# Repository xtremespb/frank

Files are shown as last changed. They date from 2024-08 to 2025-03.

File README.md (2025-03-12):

# FRANK

FRANK is a versatile hardware emulation platform based on Raspberry Pico and Raspberry Zero. It is a hardware fork of the [Murmulator](https://murmulator.ru/) project by [Alex Ekb](https://t.me/Alex_Eburg), incorporating numerous additional features.

The name "FRANK" is derived from "Frankenstein" as it integrates various components from different projects, similar to how Dr. Frankenstein created his monster from different parts. This combination enables FRANK to offer a unique and powerful set of capabilities.

## Supported Platforms

FRANK supports emulation for a variety of platforms, including:

* ZX Spectrum (48K, 128K and other models, including clones)
* IBM PC XT 8088
* BK-0011М (soviet 8 bit home computer)
* Radio 86RK (soviet 8 bit home computer)
* Atari 800
* NES/Famicom (also known as Dendy)
* Sega Master System
* Sega Game Gear
* NEC PC Engine / TurboGrafx 16
* Sega MegaDrive / Genesis
* Nintendo GameBoy
* Nintendo GameBoy Color
* Watara Supervision
* Atari Lynx
* Bandai Wonderswan
* NeoGeo Pocket Color
* Picomite MMBasic
* VersaTerm
* DOOM
* Macintosh 512K
* MurmulatorOS

## FRANK Models

Currently there are the following versions of FRANK available:

* [FRANK M1](./hardware/frank_m1) (latest hardware revision: 1.14)
* [FRANK M2](./hardware/frank_m2) (latest hardware revision: 1.02)
* [MiniFRANK RM1](./hardware/minifrank_rm1) (latest hardware revision: 2.01)
* [TurboFRANK](./hardware/turbofrank) (latest hardware revision: 1.02)

## Side Projects

* [HDMI2VGA](./hardware/hdmi2vga) - HDMI to VGA/Soft Composite passive adaptor (latest hardware revision: 2.01)
* [USB2PS2](./hardware/usb2ps2) - USB to PS/2 adapter built on RP2040-Zero (latest hardware revision: 1.03)
* [Protea](./hardware/protea) - hardware fork of [VersaTerm](https://github.com/dhansel/VersaTerm) DIY terminal built on plain RP2040 chip (latest hardware revision: 2.03)

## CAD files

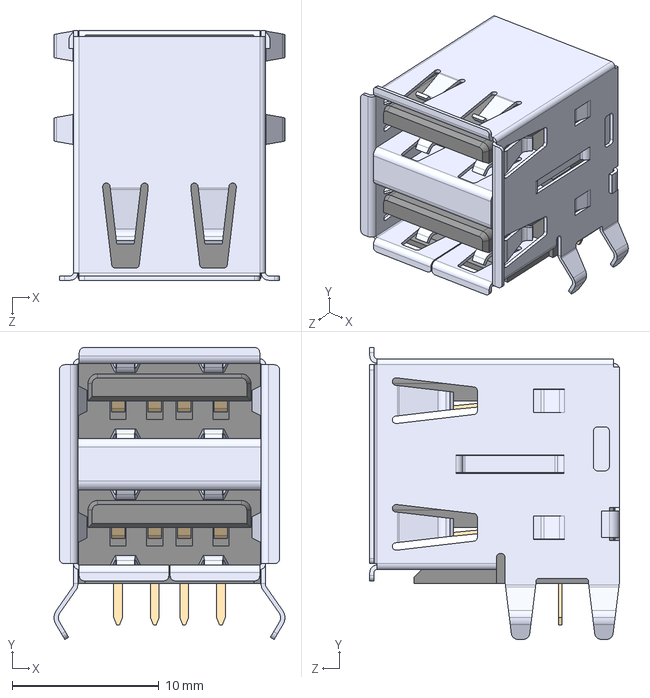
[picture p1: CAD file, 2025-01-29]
hardware/frank_rm1z/3D/USB1035-GF-P-0-B-B.stp
15.7 x 19.9 x 17.0 mm

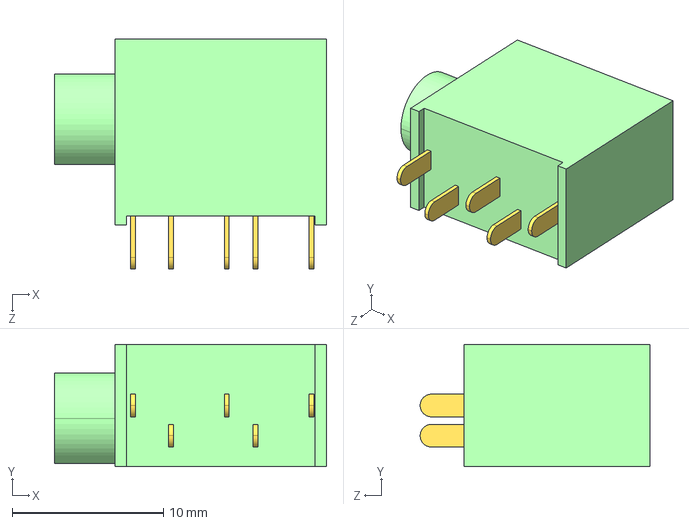
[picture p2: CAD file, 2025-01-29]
hardware/minifrank_rm1/3D/PJ325.step
18.0 x 8.10 x 15.2 mm

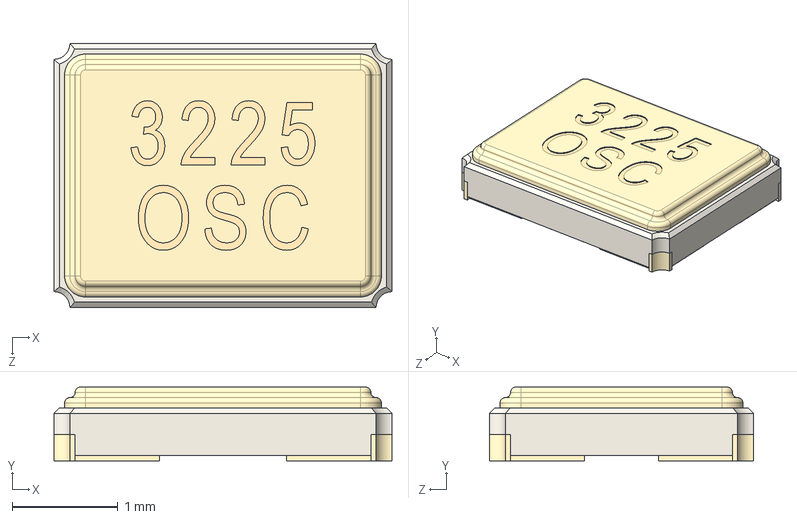
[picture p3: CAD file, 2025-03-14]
hardware/minifrank_rm24/3D/3225 SMD Crystal Oscillator.STEP
3.20 x 0.7 x 2.50 mm

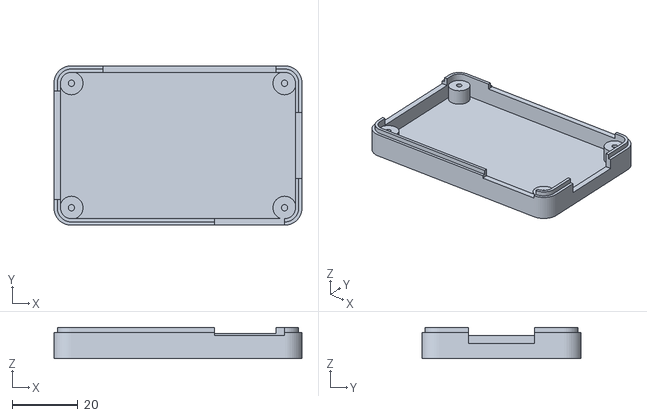
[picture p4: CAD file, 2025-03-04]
hardware/protea/CASE/2_xx/bottom.stl
75.3 x 48.4 x 9.50

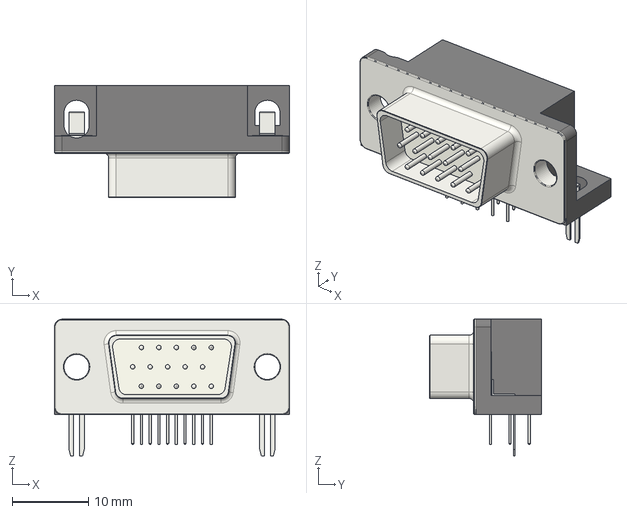
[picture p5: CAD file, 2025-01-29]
hardware/frank_rm1z/3D/DSUB-15-HD_Male_Horizontal_P2.29x1.98mm_EdgePinOffset3.03mm_Housed_MountingHolesOffset4.94mm.step
30.8 x 14.7 x 17.9 mm

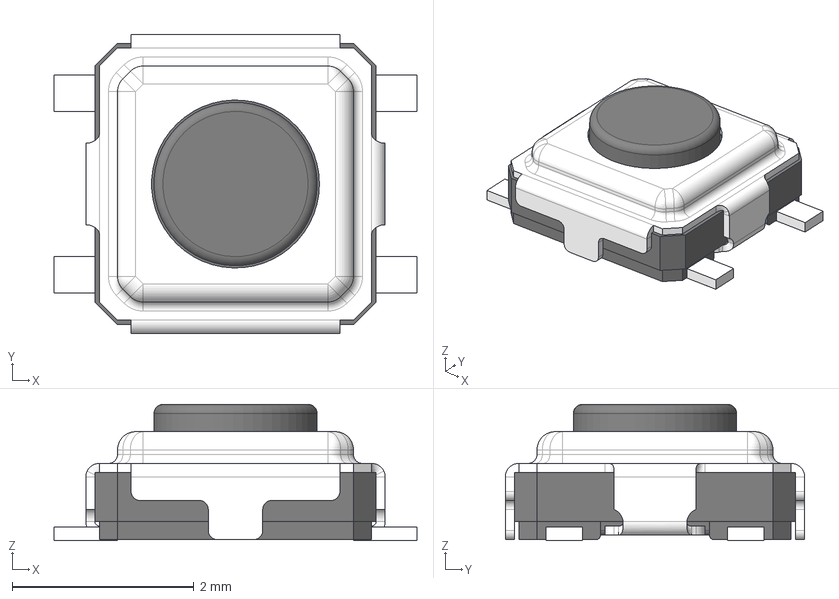
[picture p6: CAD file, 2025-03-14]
hardware/minifrank_rm24/3D/Ts-1233_1.5.stp
4.00 x 3.30 x 1.50 mm

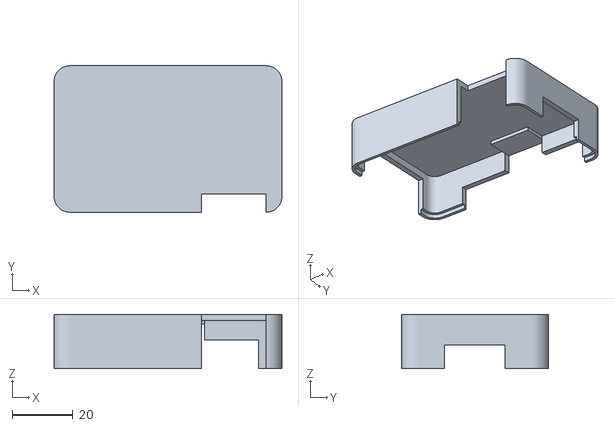
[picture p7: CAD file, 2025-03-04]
hardware/protea/CASE/2_xx/top.stl
75.3 x 48.4 x 18.0

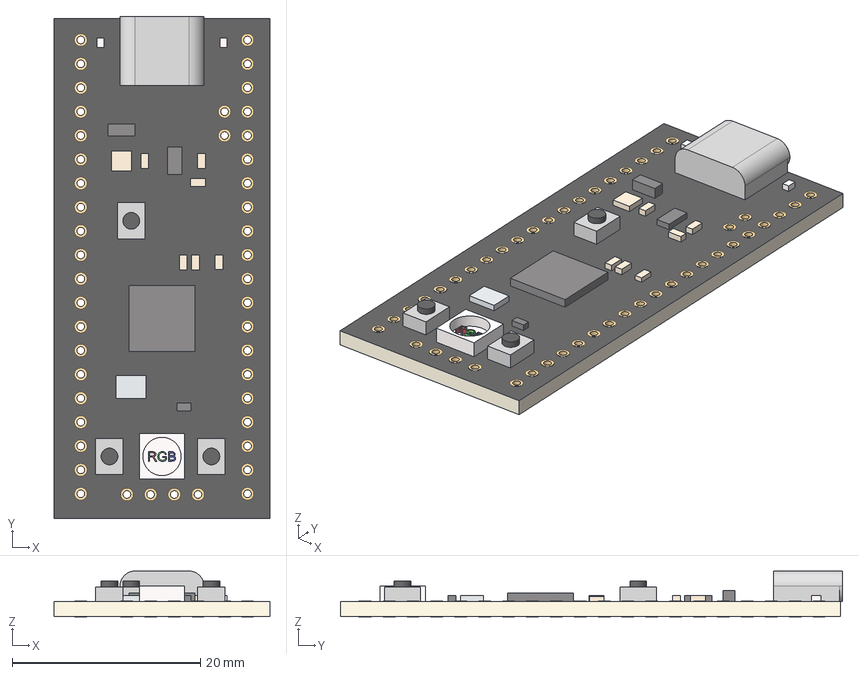
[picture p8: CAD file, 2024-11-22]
hardware/frank_rm1z/3D/PICO Clone-Black .step
22.9 x 53.3 x 4.88 mm

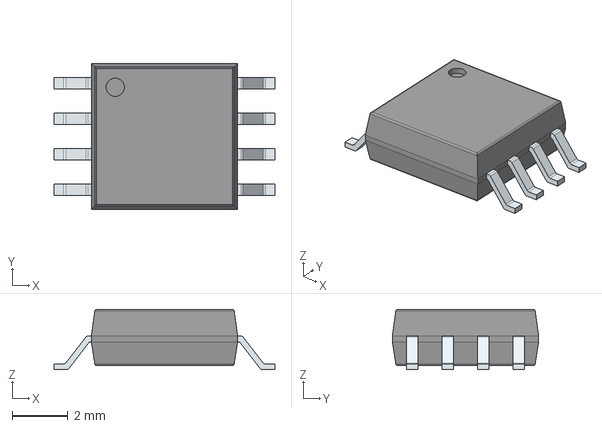
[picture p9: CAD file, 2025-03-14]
hardware/minifrank_rm24/3D/W25Q128JVSIQ.stp
7.90 x 5.23 x 2.16 mm
PinsArrayLR

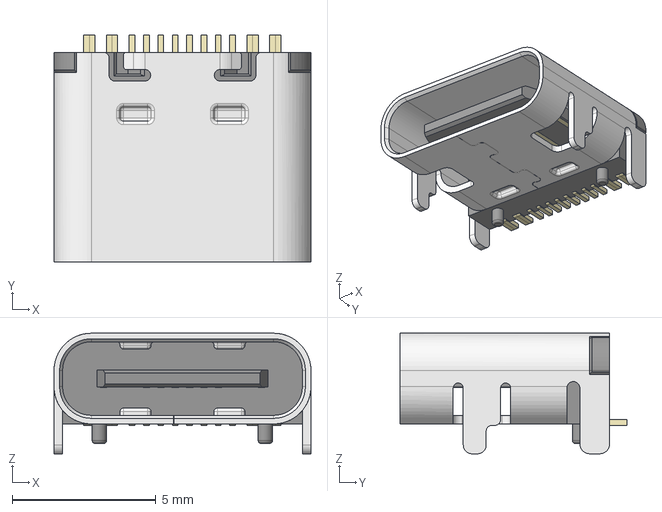
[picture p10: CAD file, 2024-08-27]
hardware/frank_rm1z/3D/HRO_TYPE-C-31-M-12.step
8.95 x 7.90 x 4.20 mm

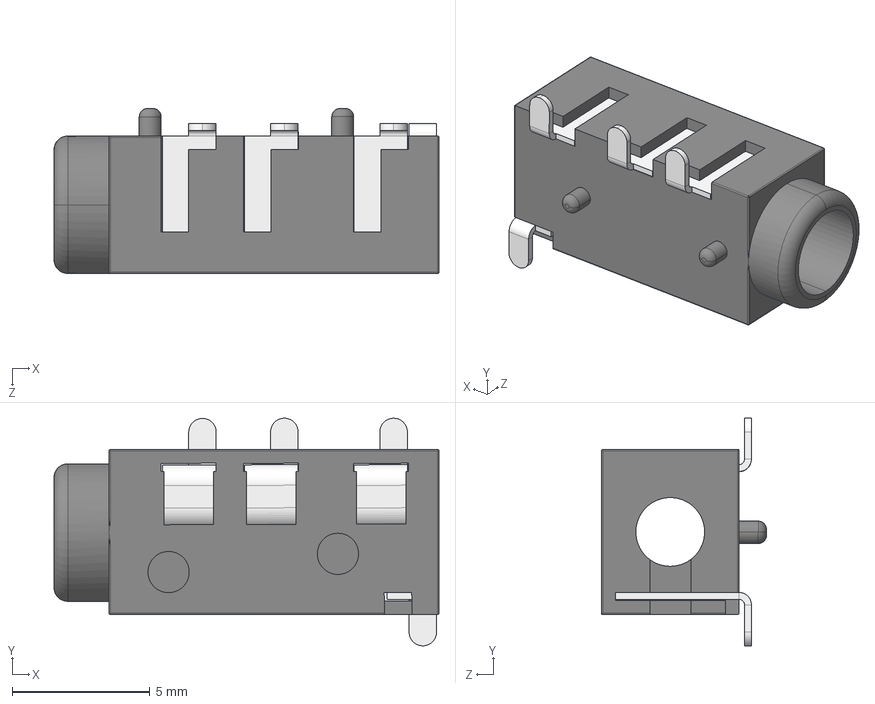
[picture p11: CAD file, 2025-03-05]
hardware/minifrank_rm24/3D/PJ320D.STEP
14.0 x 8.28 x 6.00 mm
PJ320A
PJ320D-Pin x 3
PJ320D-Pin-B

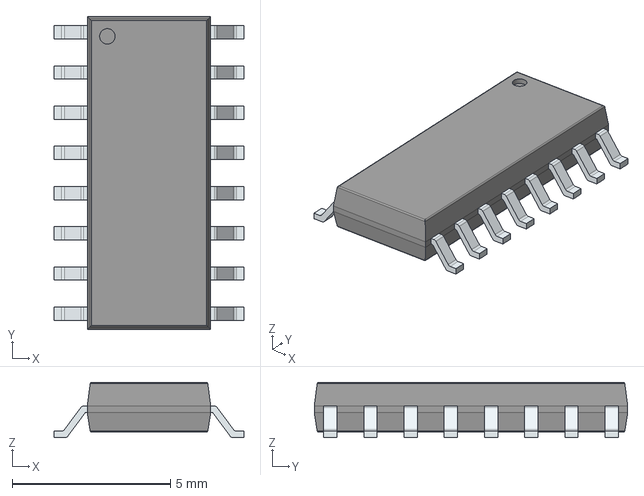
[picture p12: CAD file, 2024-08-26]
hardware/frank_rm1z/3D/MAX232CSE+.stp
6.00 x 9.90 x 1.75 mm
PinsArrayLR

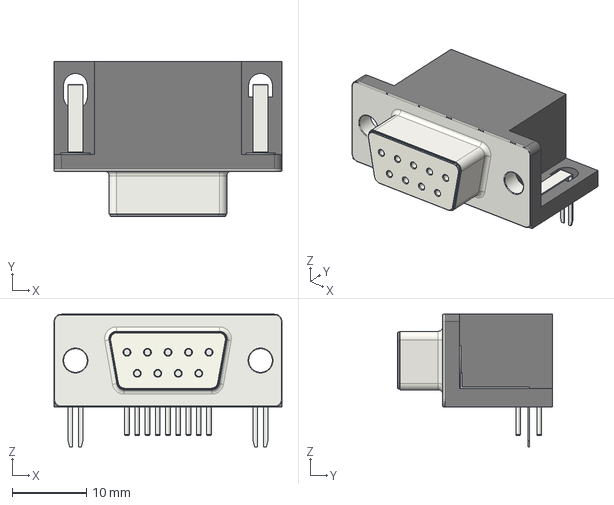
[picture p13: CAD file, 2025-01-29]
hardware/minifrank_rm24/3D/DSUB-9_Female_Horizontal_P2.77x2.84mm_EdgePinOffset9.90mm_Housed_MountingHolesOffset11.32mm.step
30.8 x 20.9 x 17.9 mm

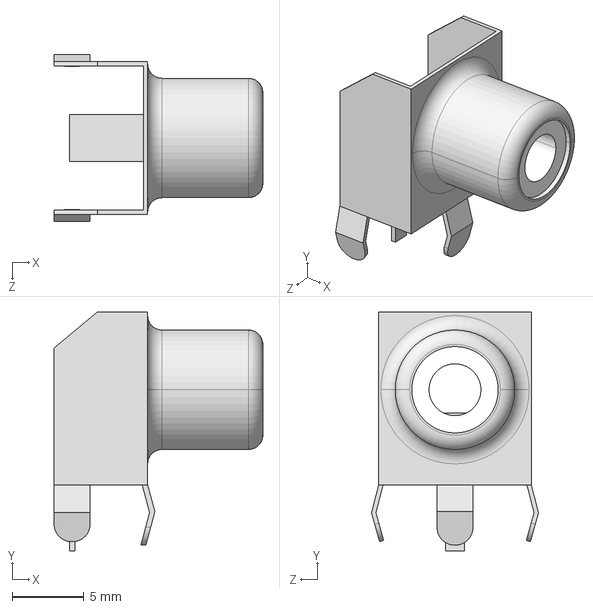
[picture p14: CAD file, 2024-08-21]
hardware/frank_rm1z/3D/CUI_DEVICES_RCJ-013.step
14.5 x 16.6 x 11.6 mm

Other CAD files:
hardware/frank_rm1z/3D/Mini-DIN-6P.step
hardware/frank_rm1z/3D/SJ1-3535NG.stp
hardware/minifrank_rm24/3D/SJ1-3535NG.stp
hardware/frank/3D/Mini-DIN-6P.step
hardware/frank/3D/SJ1-3535NG.stp
hardware/minifrank/3D/Mini-DIN-6P.step
hardware/minifrank/3D/SJ1-3535NG.stp
hardware/minifrank_rm1/3D/Mini-DIN-6P.step
hardware/minifrank_rm1/3D/SJ1-3535NG.stp
hardware/minifrank_rm1/CASE/bottom.stl
hardware/minifrank_rm1/CASE/top.stl
hardware/minifrank_rm24/3D/47571-0001.stp
hardware/minifrank_rm24/3D/Mini-DIN-6P.step
hardware/turbofrank/CASE/bottom.stl
hardware/turbofrank/CASE/top.stl
hardware/usb2ps2/3D/Mini-DIN-6P.step
hardware/usb2ps2/3D/SJ1-3535NG.stp
hardware/usb2ps2/CASE/REV_1_0/bottom.stl
hardware/usb2ps2/CASE/REV_1_0/top.stl
hardware/valera/3D/Mini-DIN-6P.step

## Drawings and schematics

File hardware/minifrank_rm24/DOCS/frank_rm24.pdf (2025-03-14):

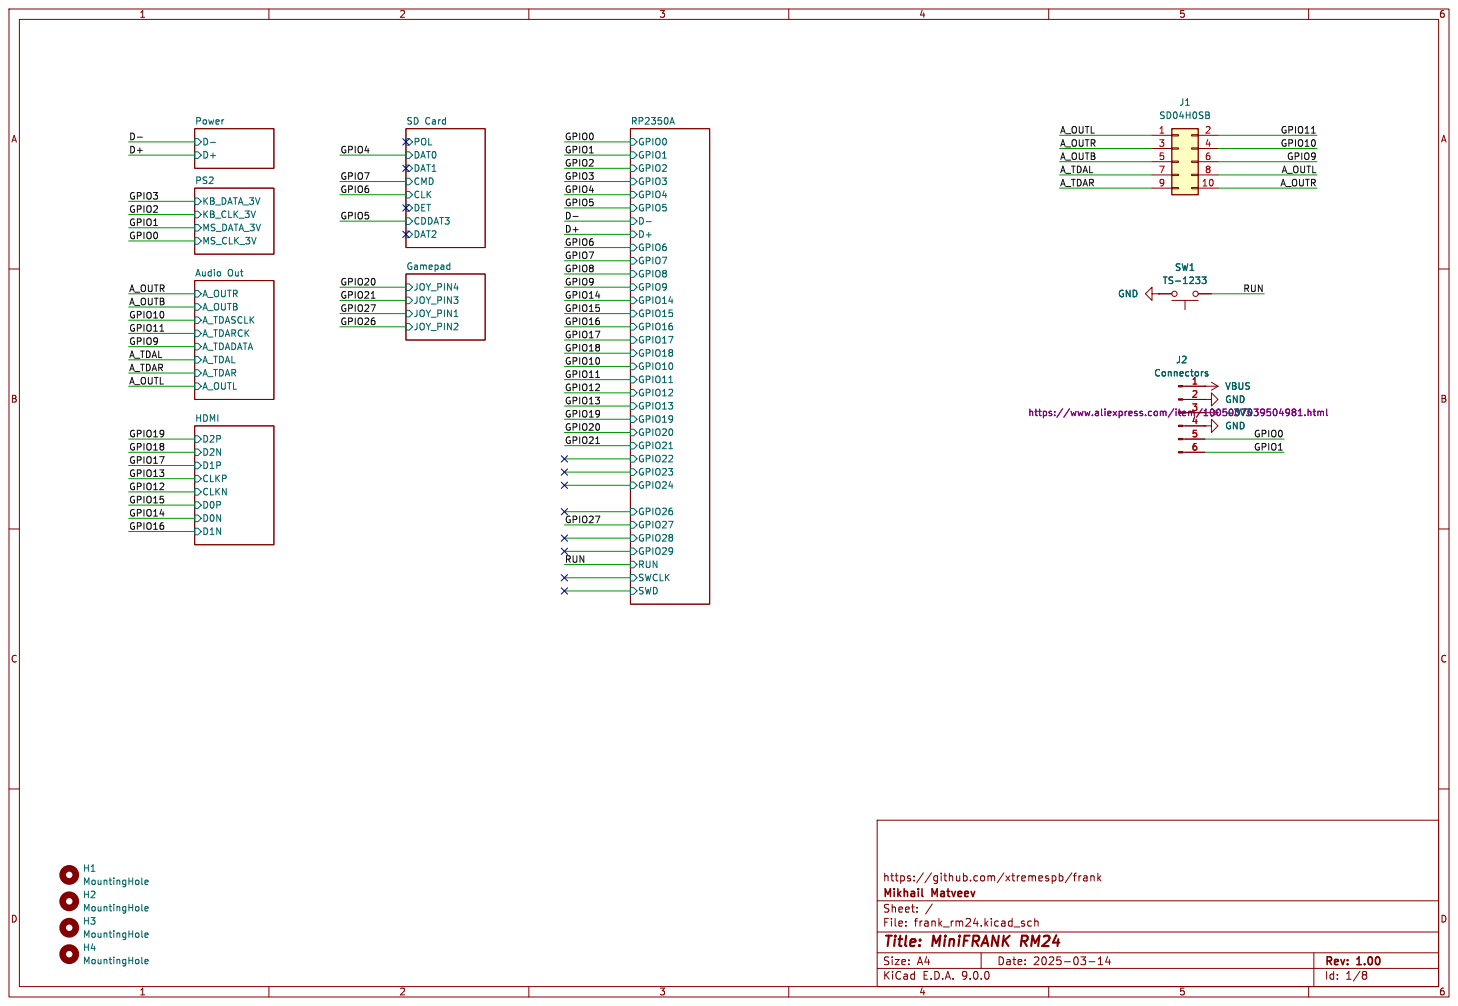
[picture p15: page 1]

J2 Connectors https://www.aliexpress.com/item/1005007039504981.html 123456 GND

https://github.com/xtremespb/frank

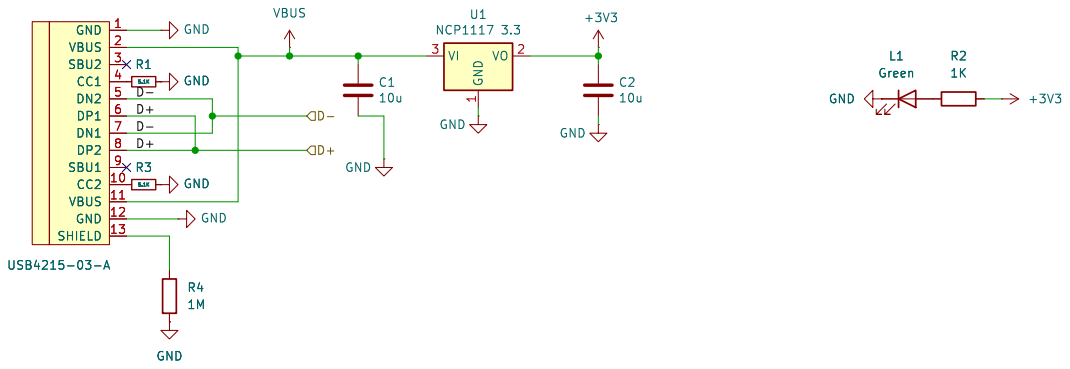
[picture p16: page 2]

https://github.com/xtremespb/frank

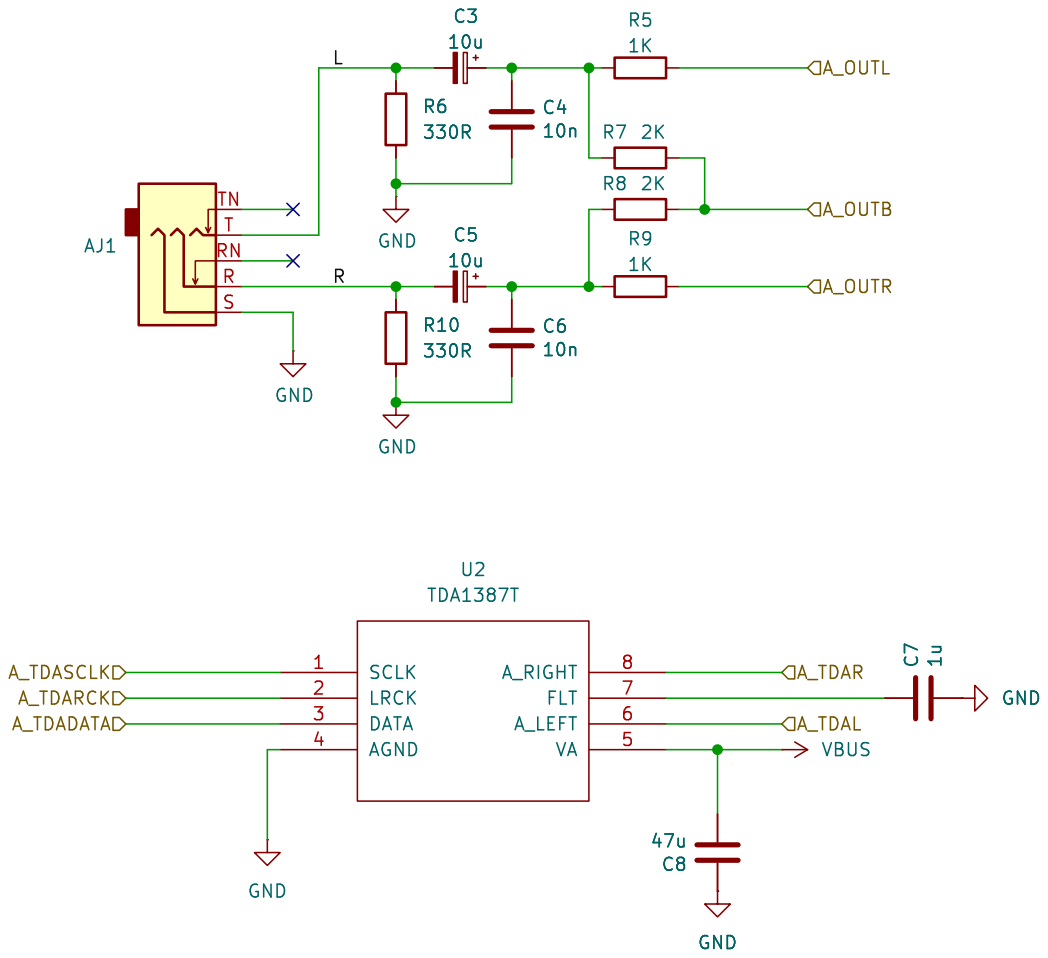
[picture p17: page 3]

https://github.com/xtremespb/frank

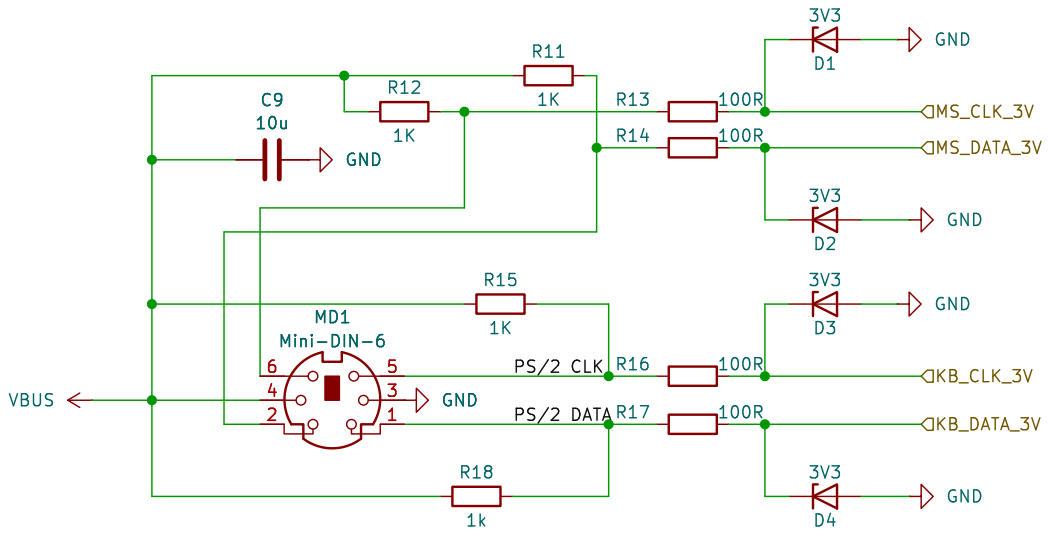
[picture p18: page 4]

PS/2 CLK MD1 Mini-DIN-6

https://github.com/xtremespb/frank

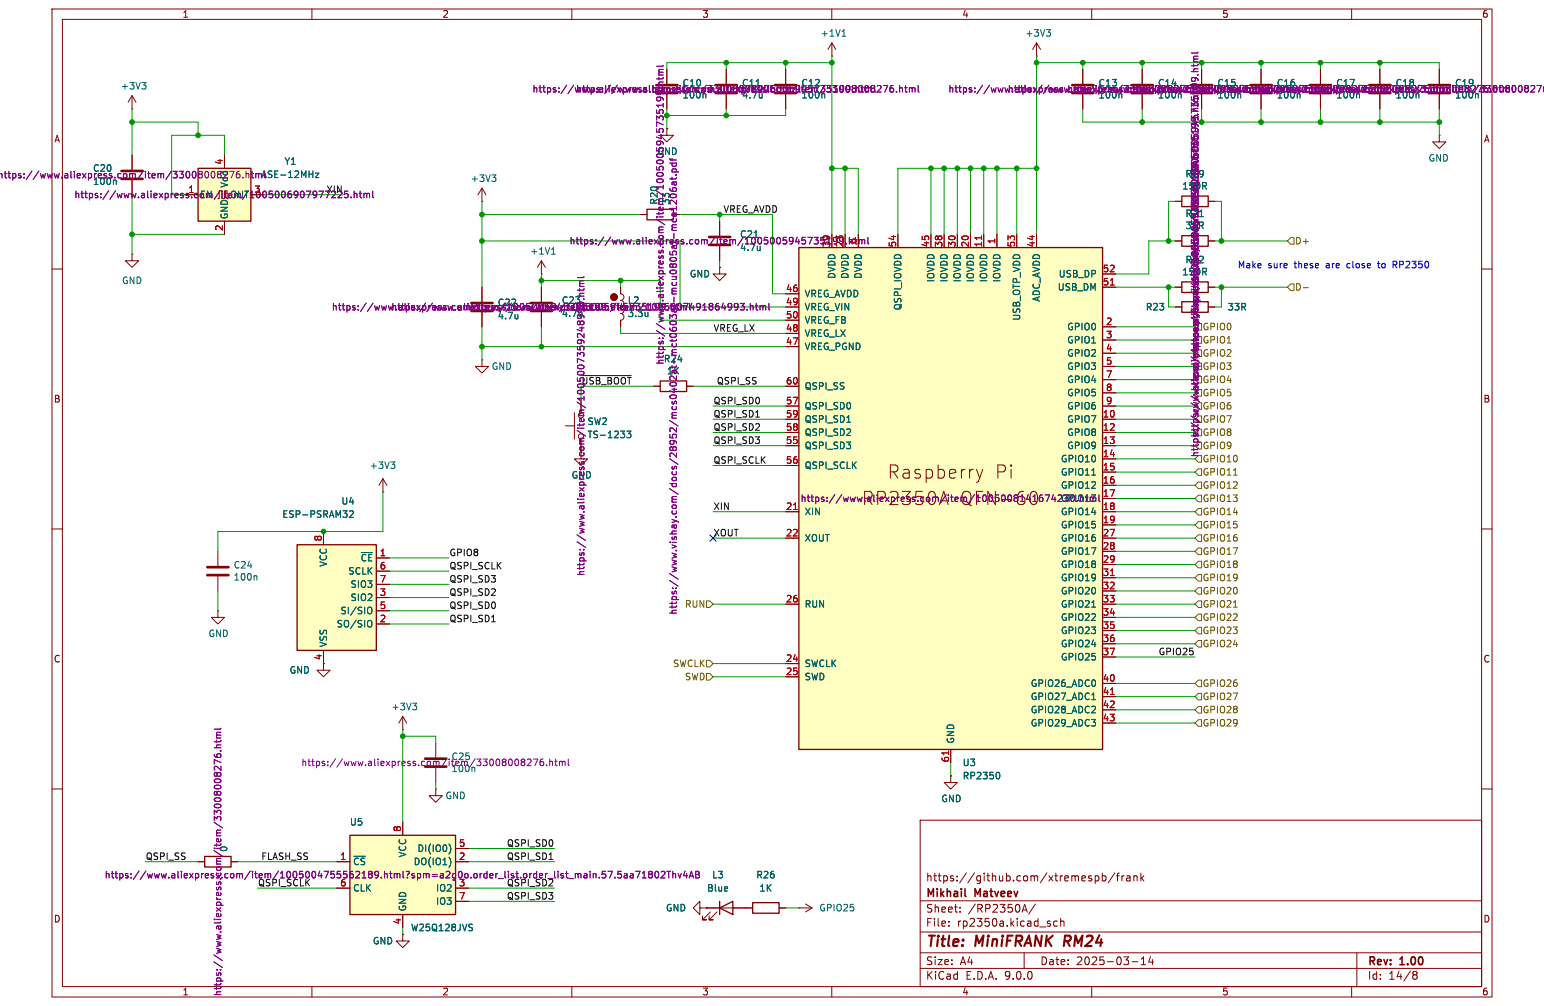
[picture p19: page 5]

100n https://www.aliexpress.com/item/33008008276.html GND GND

https://www.aliexpress.com/item/1005005945735199.html C11

4.7u https://www.aliexpress.com/item/1005005945735199.html C10

100n https://www.aliexpress.com/item/33008008276.htmlC14
100n GND

100n https://www.aliexpress.com/item/33008008276.html C14

100n https://www.aliexpress.com/item/33008008276.htmlC17

100n https://www.aliexpress.com/item/33008008276.html C16
150Rhttps://www.aliexpress.com/item/1005005945735199.html R21

100n https://www.aliexpress.com/item/33008008276.htmlC19

100n https://www.aliexpress.com/item/33008008276.html C18

100n https://www.aliexpress.com/item/33008008276.html
1Khttps://www.vishay.com/docs/28952/mcs0402at-mct0603at-mcu0805at-mca1206at.pdf C23

2 OUT 3 Y1 ASE-12MHz https://www.aliexpress.com/item/1005006907977225.html

6 QSPI_IOVDD 54 IOVDD 45 IOVDD 38 GND 61 IOVDD 30 IOVDD 20 IOVDD 11 IOVDD

https://www.aliexpress.com/item/1005007491864993.html

https://www.aliexpress.com/item/1005005945735199.html C22
https://www.aliexpress.com/item/1005007491864993.html GND

0 https://www.aliexpress.com/item/33008008276.html U4 ESP-PSRAM32 VCC

4 ~{CE}1 SCLK 6 SIO3 7 SIO2 3 SI/SIO 5 SO/SIO 2 U4 ESP-PSRAM32 R26

4 ~{CE}1 SCLK 6 SIO3 7 SIO2 3 SI/SIO 5 SO/SIO 2 GND

https://github.com/xtremespb/frank C24

100n https://www.aliexpress.com/item/33008008276.html +3V3

0 https://www.aliexpress.com/item/33008008276.html L3 Blue GND GPIO25

https://www.aliexpress.com/item/1005004755562189.html?spm=a2g0o.order_list.order_list_main.57.5aa71802Thv4AB

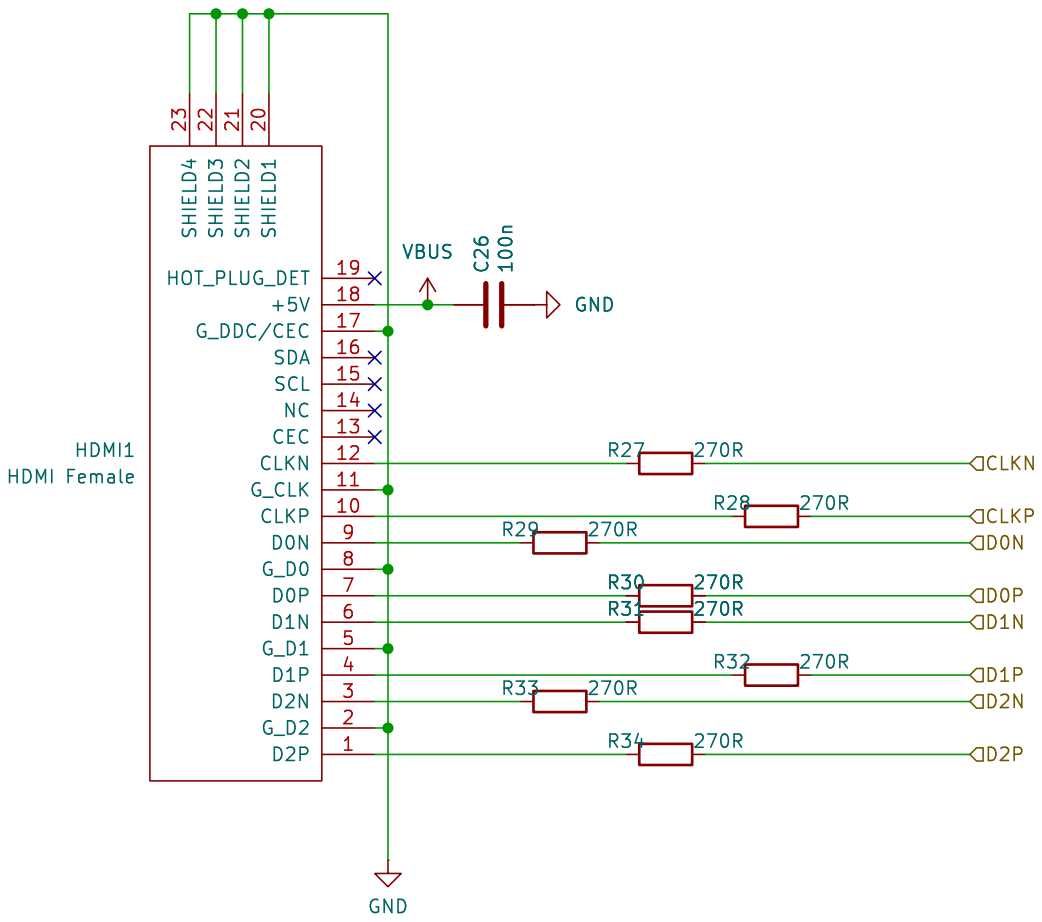
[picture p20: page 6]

https://github.com/xtremespb/frank

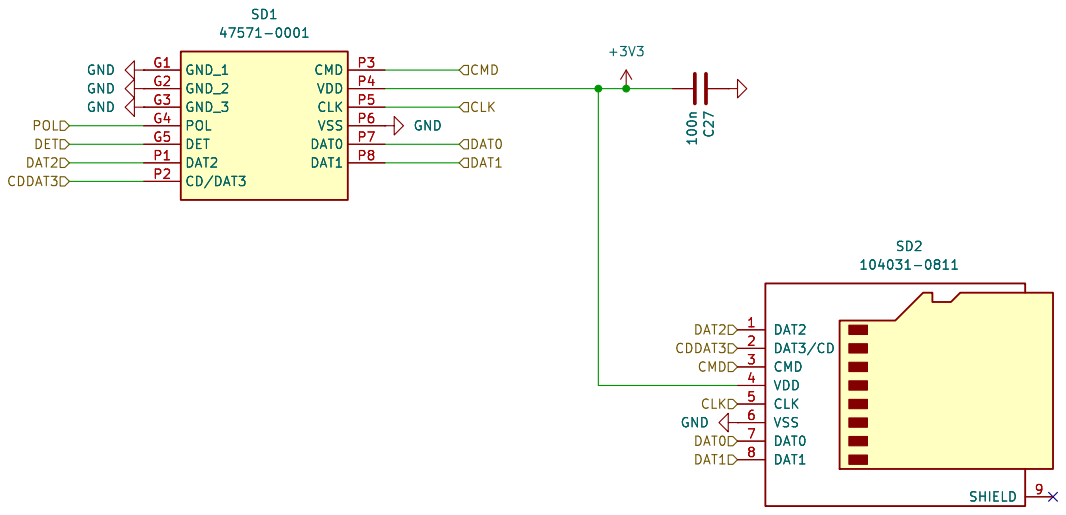
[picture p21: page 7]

https://github.com/xtremespb/frank

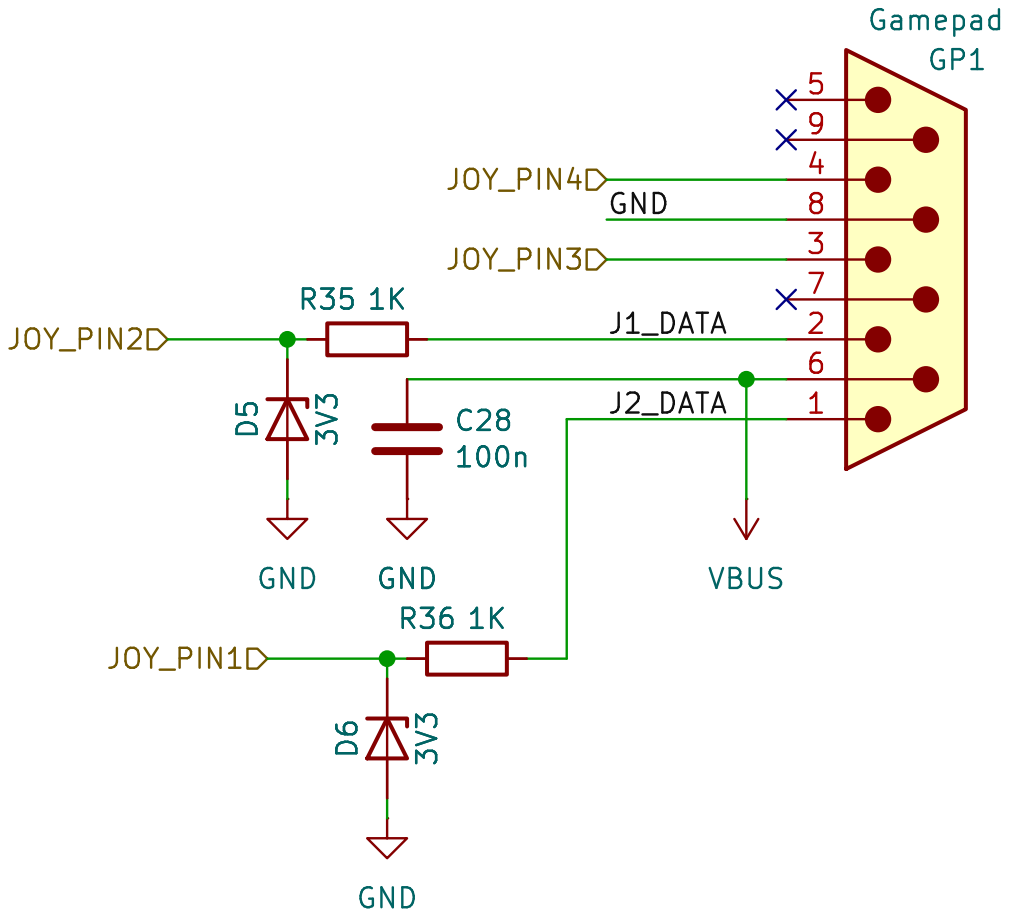
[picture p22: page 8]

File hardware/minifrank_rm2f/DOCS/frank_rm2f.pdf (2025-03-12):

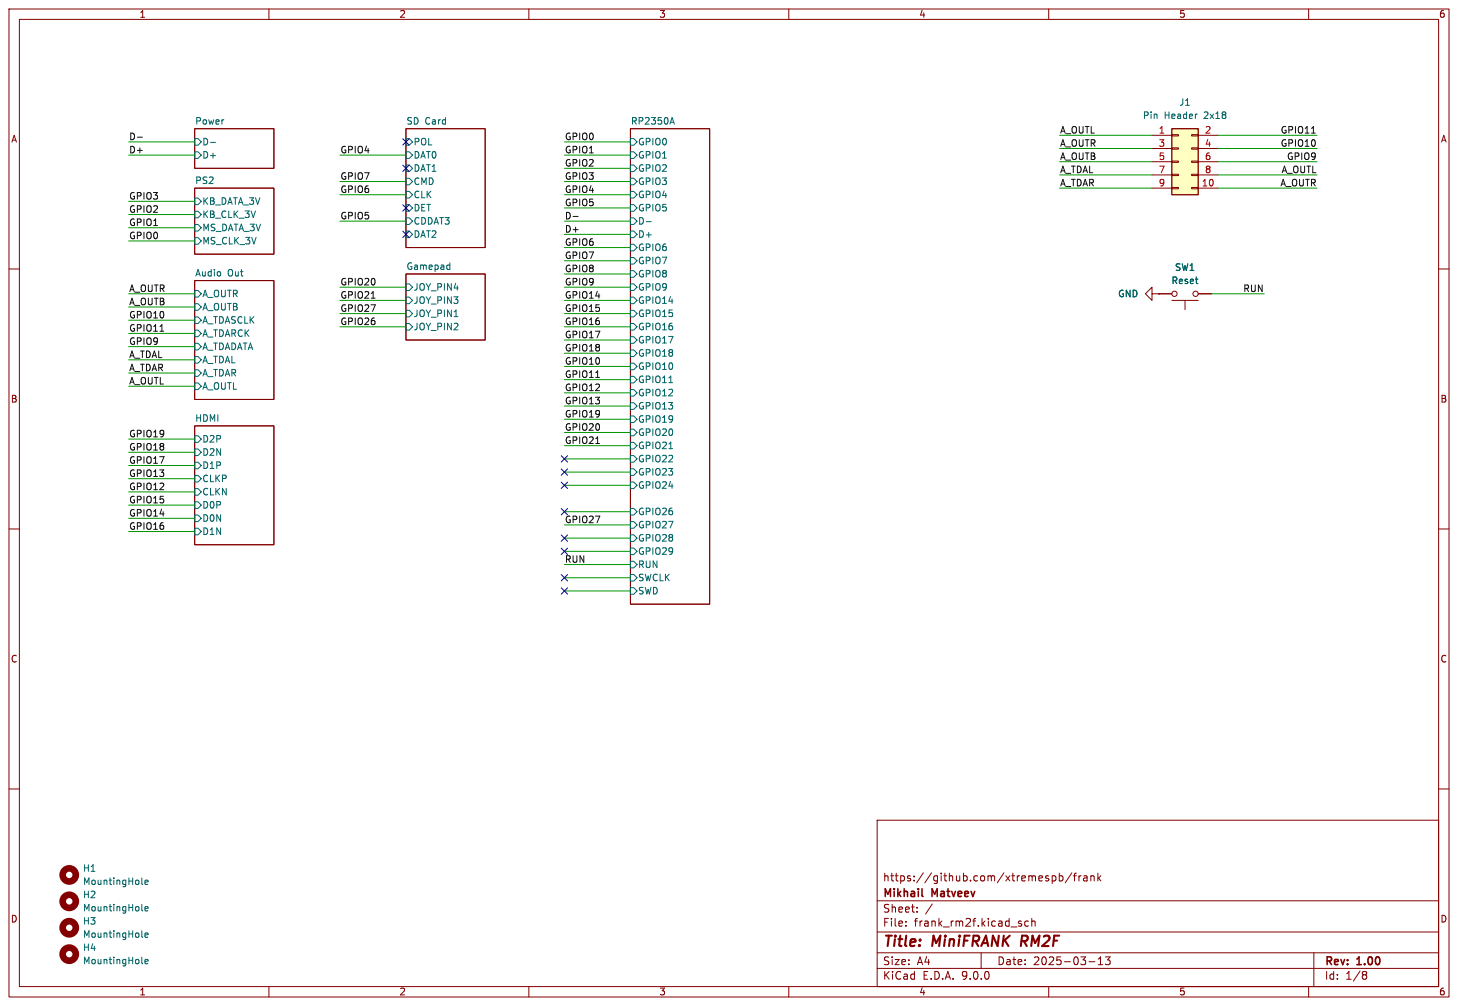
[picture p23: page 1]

CLK DET CDDAT3 DAT2 SD Card KB_DATA_3V

H3 MountingHole H4 MountingHole H2 MountingHole H1 MountingHole

https://github.com/xtremespb/frank

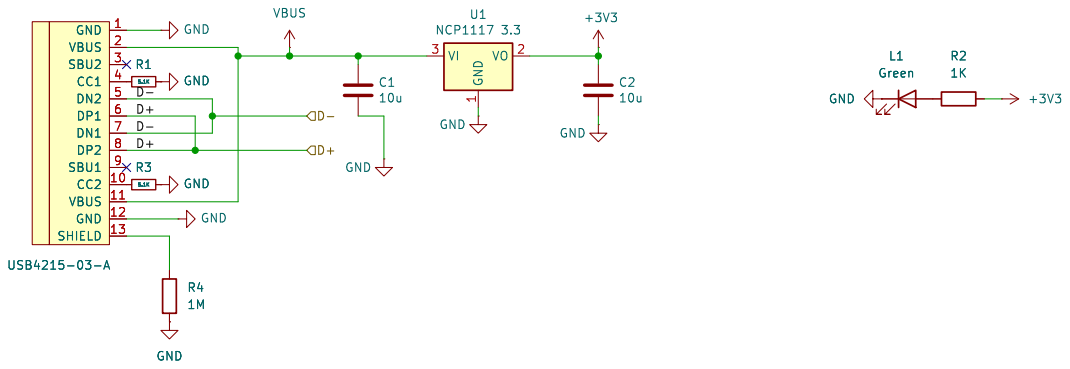
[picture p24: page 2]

https://github.com/xtremespb/frank

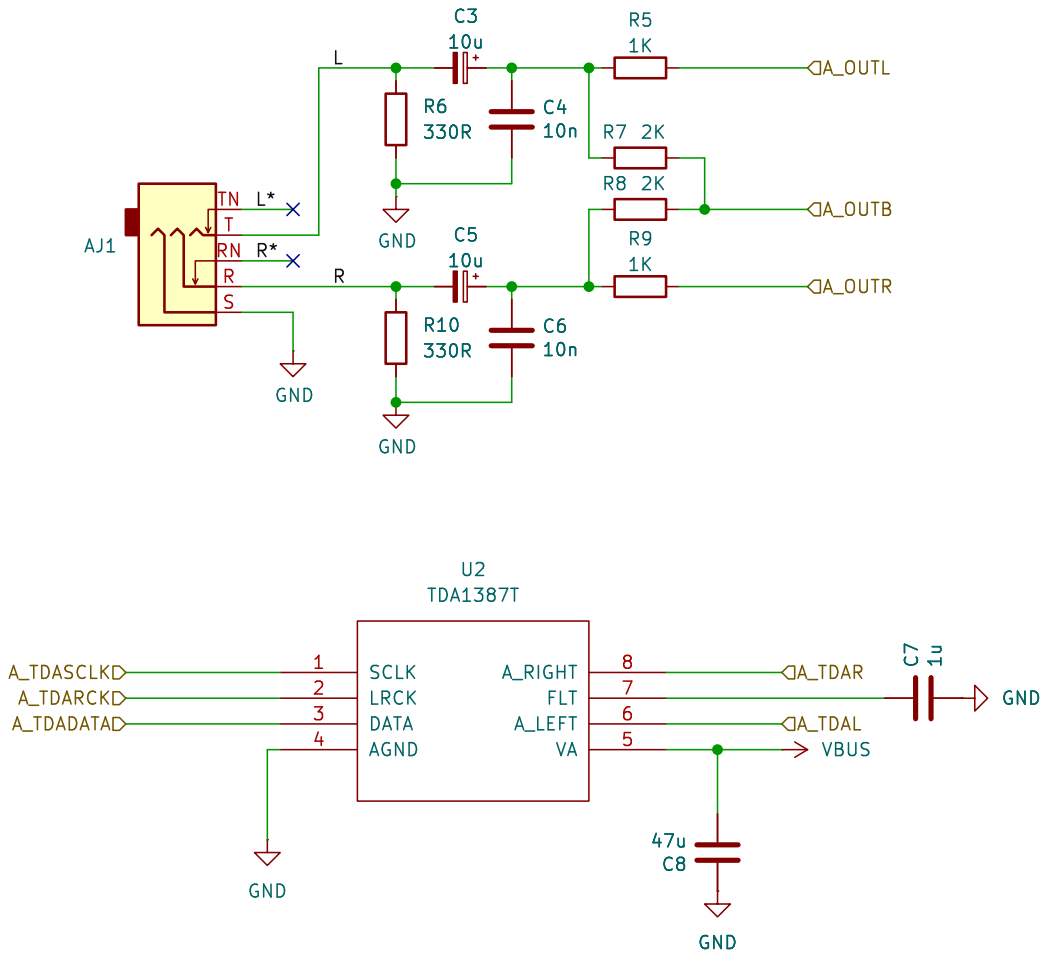
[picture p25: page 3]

https://github.com/xtremespb/frank GND


PS/2 CLK MD1 Mini-DIN-6

https://github.com/xtremespb/frank

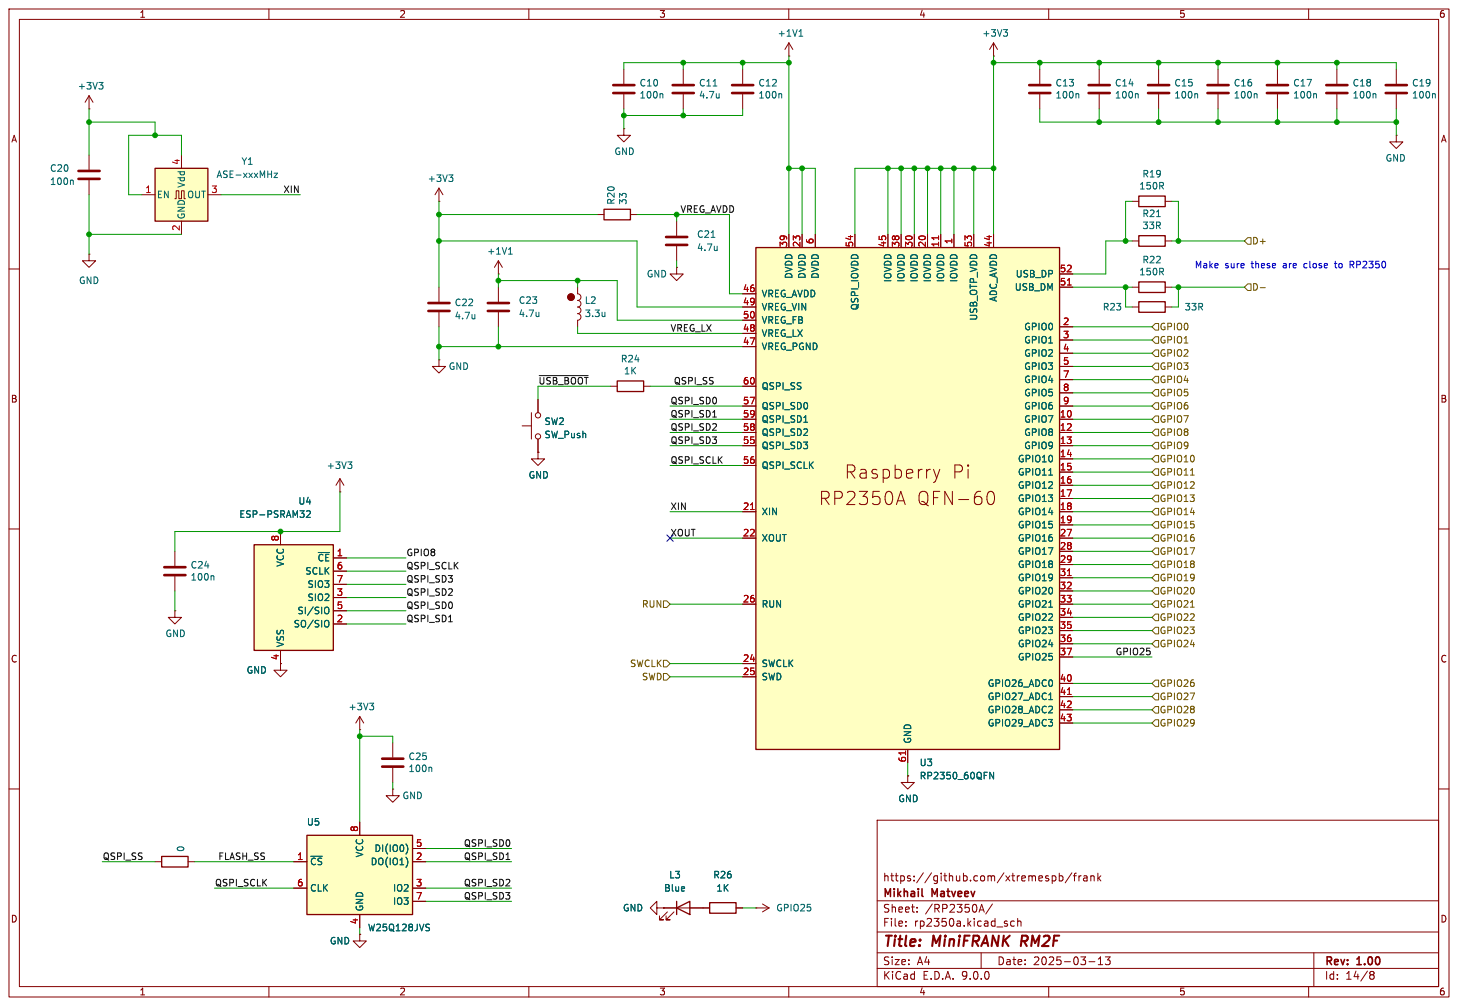
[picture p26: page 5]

6 QSPI_IOVDD 54 IOVDD 45 IOVDD 38 GND 61 IOVDD 30 IOVDD 20 IOVDD 11 IOVDD

4 ~{CE}1 SCLK 6 SIO3 7 SIO2 3 SI/SIO 5 SO/SIO 2 U4 ESP-PSRAM32 GND

4 ~{CE}1 SCLK 6 SIO3 7 SIO2 3 SI/SIO 5 SO/SIO 2 U3 RP2350_60QFN

https://github.com/xtremespb/frank GND


https://github.com/xtremespb/frank


https://github.com/xtremespb/frank


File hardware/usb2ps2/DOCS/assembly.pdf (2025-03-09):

# C2 3V3 D3


D Date: 2025-03-09 KiCad; E.D.A. 9.0.0 Size: A4; Rev: 1.03; Id: /1 Title: USB to PS/2; Adapter File: usb2ps2.kicad_pcb Sheet: Black; And; White; BOT Mikhail; Matveev; https://github.com/xtremespb/frank Black; BOT -; Page 2/2

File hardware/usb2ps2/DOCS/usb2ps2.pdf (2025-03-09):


H4 MountingHole H3 MountingHole H1 MountingHole H2 MountingHole

https://github.com/xtremespb/frank


https://github.com/xtremespb/frank



https://github.com/xtremespb/frank


https://github.com/xtremespb/frank

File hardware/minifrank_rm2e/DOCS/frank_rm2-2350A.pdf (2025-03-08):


CLK DET CDDAT3 DAT2 SD Card KB_DATA_3V

H2 MountingHole H3 MountingHole H4 MountingHole H1 MountingHole

https://github.com/xtremespb/frank


https://github.com/xtremespb/frank


https://github.com/xtremespb/frank GND


PS/2 CLK MD1 Mini-DIN-6

https://github.com/xtremespb/frank


6 QSPI_IOVDD 54 IOVDD 45 IOVDD 38 GND 61 IOVDD 30 IOVDD 20 IOVDD 11 IOVDD

4 ~{CE}1 SCLK 6 SIO3 7 SIO2 3 SI/SIO 5 SO/SIO 2 U4 ESP-PSRAM32 ~{CS} 1 CLK 6 VCC

4 ~{CE}1 SCLK 6 SIO3 7 SIO2 3 SI/SIO 5 SO/SIO 2 GND

https://github.com/xtremespb/frank GND


https://github.com/xtremespb/frank


https://github.com/xtremespb/frank


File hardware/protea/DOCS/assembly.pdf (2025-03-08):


D Date: 2025-03-08 KiCad; E.D.A. 9.0.0 Size: A4; Rev: 2.03; File: protea.kicad_pcb Sheet: Black; And; White; BOT Mikhail; Matveev; https://github.com/xtremespb/frank Black; BOT -; Page 2/2

Id: /1 Title: Protea

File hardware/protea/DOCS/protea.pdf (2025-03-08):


https://github.com/xtremespb/frank RS232_TX RS232_RTS RS232_RX RS232_CTS RS232 PS2_KB_CLK
PS2_KB_DATA

D2P HDMI D- D+ USB A H1 MountingHole H4 MountingHole H2 MountingHole H3 MountingHole


4 FL1 W25Q128JVSIQGND
~{CS} 1 CLK 6 DI(IO0) 5 DO(IO1) 2

4 SW1 Flash Button GND C15 15p C14 15p GND

https://github.com/xtremespb/frank


Usually it's green, but you decide ;-) GND

https://github.com/xtremespb/frank


https://github.com/xtremespb/frank


https://github.com/xtremespb/frank


https://github.com/xtremespb/frank


https://github.com/xtremespb/frank


https://github.com/xtremespb/frank GND


https://github.com/xtremespb/frank

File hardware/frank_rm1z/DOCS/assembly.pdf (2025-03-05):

J2 1 | 2 | 3 | 4 | 5 | 6 1 | 2 | 3 | 4 | 5 | 6 ABCD | ABCD Date: 2025-03-06 KiCad | E.D.A. 9.0.0 Size: A4 | Rev: 1.00


https://github.com/xtremespb/frank Black And White TOP - Page 1/2

File: frank_rm1z.kicad_pcb Sheet: Black And White TOP Mikhail Matveev

1 | 2 | 3 | 4 | 5 | 6

A

D Date: 2025-03-06 KiCad; E.D.A. 9.0.0 Size: A4; Rev: 1.00; File: frank_rm1z.kicad_pcb Sheet: Black; And; White; BOT Mikhail; Matveev; https://github.com/xtremespb/frank Black; BOT -; Page 2/2; Jumper (Solder)

Id: /1 Title: FRANK RM1Z

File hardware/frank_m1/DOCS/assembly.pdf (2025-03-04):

R2 SW1 C6 | C9 1 | 2 | 3 | 4 | 5 | 6 1 | 2 | 3 | 4 | 5 | 6 ABCD | ABCD Date: 2025-03-03 KiCad E.D.A. 9.0.0 Size: A4 | Rev: 1.14


https://github.com/xtremespb/frank Black And White TOP - Page 1/2

File: CMZJ2.kicad_pcb Sheet: Black And White TOP Mikhail Matveev

JP2 1 | 2 | 3 | 4 | 5 | 6

A

D Date: 2025-03-03 KiCad; E.D.A. 9.0.0 Size: A4; Rev: 1.14; File: CMZJ2.kicad_pcb Sheet: Black; And; White; BOT Mikhail; Matveev; https://github.com/xtremespb/frank Black; BOT -; Page 2/2; Jumper (Solder)

Id: /1 Title: FRANK M1

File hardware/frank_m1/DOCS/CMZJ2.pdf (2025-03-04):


Tape In D2+ D1- D1+ D2- USB Stacked CLKN

DAT0 CLK DAT2 DET CDDAT3 POL DAT1 Micro SD

https://github.com/xtremespb/frank


https://github.com/xtremespb/frank



https://github.com/xtremespb/frank


https://github.com/xtremespb/frank


https://github.com/xtremespb/frank


https://github.com/xtremespb/frank


https://github.com/xtremespb/frank


4 ~{CE}1 SCLK 6 SIO3 7 SIO2 3 SI/SIO 5 SO/SIO 2 PSR1 ESP-PSRAM32 GND GND

4 ~{CE}1 SCLK 6 SIO3 7 SIO2 3 SI/SIO 5 SO/SIO 2 GND GND

https://github.com/xtremespb/frank


https://github.com/xtremespb/frank


https://github.com/xtremespb/frank


https://github.com/xtremespb/frank


https://github.com/xtremespb/frank


https://github.com/xtremespb/frank


https://github.com/xtremespb/frank


https://github.com/xtremespb/frank


https://github.com/xtremespb/frank


https://github.com/xtremespb/frank

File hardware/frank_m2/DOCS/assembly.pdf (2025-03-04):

# AV8.4-5 D-SUB 9 Male GP2 D-SUB 9 Male GP1


https://github.com/xtremespb/frank Black And White TOP - Page 1/2

File: HR3FQ.kicad_pcb Sheet: Black And White TOP Mikhail Matveev

D Date: 2025-02-19 KiCad; E.D.A. 9.0.0 Size: A4; Rev: 1.02; File: HR3FQ.kicad_pcb Sheet: Black; And; White; BOT Mikhail; Matveev; https://github.com/xtremespb/frank Black; BOT -; Page 2/2; Jumper (Solder)

Id: /1 Title: FRANK M2

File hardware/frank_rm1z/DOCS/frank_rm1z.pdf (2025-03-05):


DAT0 CLK DAT2 DET CDDAT3 POL DAT1 Micro SD
D2+ D1- D1+ D2- USB Stacked CLKN
D0P CLKP D0N

https://github.com/xtremespb/frank


https://github.com/xtremespb/frank


https://github.com/xtremespb/frank GND


https://github.com/xtremespb/frank


https://github.com/xtremespb/frank


https://github.com/xtremespb/frank


4 ~{CE}1 SCLK 6 SIO3 7 SIO2 3 SI/SIO 5 SO/SIO 2 +3V3

4 ~{CE}1 SCLK 6 SIO3 7 SIO2 3 SI/SIO 5 SO/SIO 2 PSR1 ESP-PSRAM32 GND

https://github.com/xtremespb/frank


https://github.com/xtremespb/frank


https://github.com/xtremespb/frank


https://github.com/xtremespb/frank


https://github.com/xtremespb/frank


https://github.com/xtremespb/frank

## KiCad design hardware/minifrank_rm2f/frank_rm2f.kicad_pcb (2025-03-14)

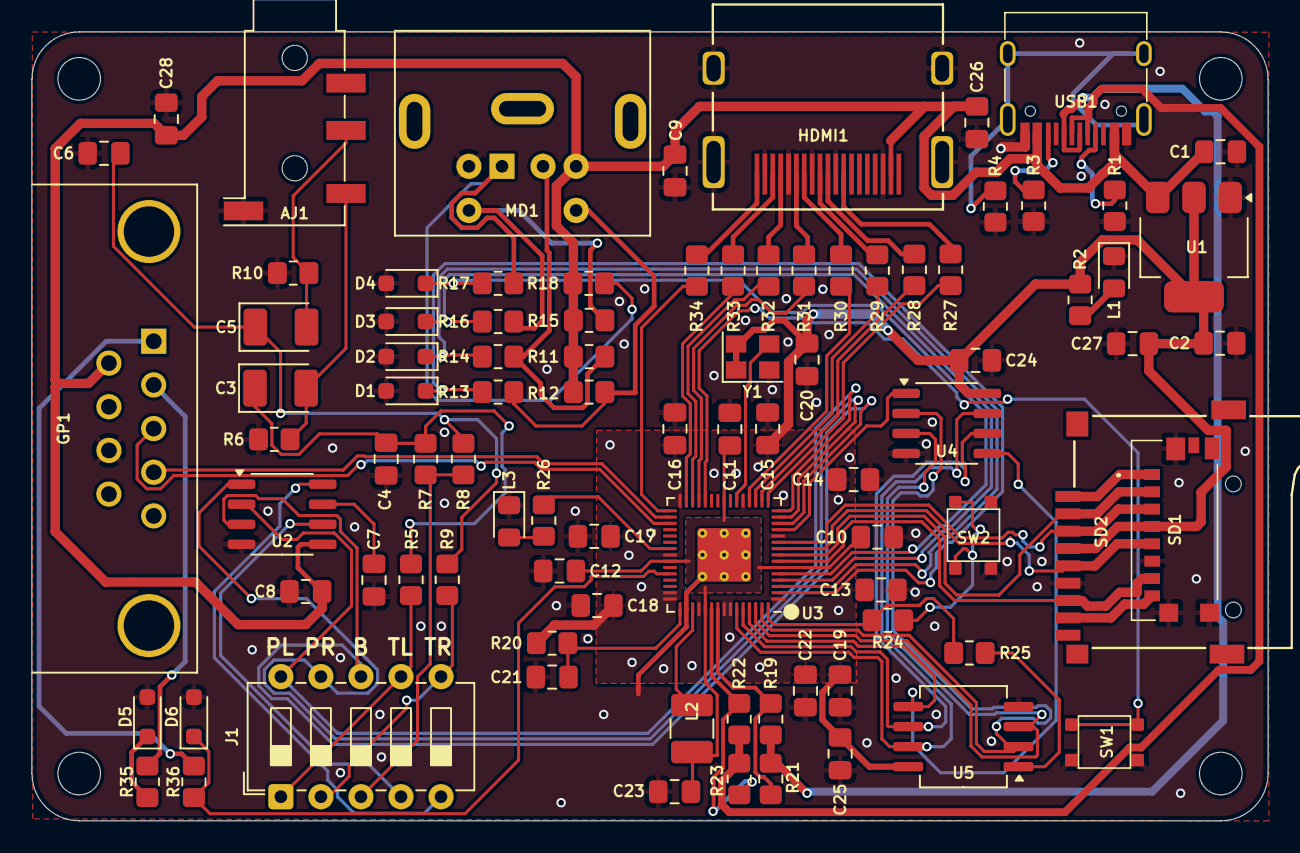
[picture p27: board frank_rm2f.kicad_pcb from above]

Board: 2 copper layers, 78.4 x 50.0 mm, 93 parts (0 on the bottom side), 76 nets.

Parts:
AJ1: SJ1-353XNG; Jack (3.5mm, PJ-320D)
C1, C2, C9: 10u; Capacitor (0805)
C3, C5: 10u; Capacitor (3528, tantalum, polar)
C4, C6: 10n; Capacitor (0805)
C7: 1u; Capacitor (0805)
C8: 47u; Capacitor (0805)
C10, C12, C13, C14, C15, C16, C17, C18, C19, C20, C24, C25, C26, C27, C28: 100n; Capacitor (0805)
C11, C21, C22, C23: 4.7u; Capacitor (0805)
D1, D2, D3, D4, D5, D6: 3V3; Diode (SOD-323)
GP1: Gamepad; D-SUB (9 pin, male, top mount)
H1, H2, H3, H4: MountingHole; Mounting Hole (2.7mm)
HDMI1: HDMI Female; HDMI (female)
J1: Pin Header 2x18; DIP Switch (5x5)
L1: Green; LED (0805)
L2: 3.3u; Inductor (3225)
L3: Blue; LED (0805)
MD1: Mini-DIN-6; MiniDIN (6 Pin, female)
R1, R3: 5.1K; Resistor (0805)
R2, R5, R9, R11, R12, R15, R24, R26, R35, R36: 1K; Resistor (0805)
R4: 1M; Resistor (0805)
R6, R10: 330R; Resistor (0805)
R7, R8: 2K; Resistor (0805)
R13, R14, R16, R17: 100R; Resistor (0805)
R18: 1k; Resistor (0805)
R19, R22: 150R; Resistor (0805)
R20: 33; Resistor (0805)
R21, R23: 33R; Resistor (0805)
R25: 0; Resistor (0805)
R27, R28, R29, R30, R31, R32, R33, R34: 270R; Resistor (0805)
SD1: 47571-0001; MicroSD (SMD, short)
SD2: 104031-0811; MicroSD (SMD, long)
SW1: Reset; Button (SMD, 3x3mm, 1-1)
SW2: SW_Push; Button (SMD, 3x3mm, 1-1)
U1: NCP1117 3.3; SOT-223
U2: TDA1387T; SO-8
U3: RP2350_60QFN; QFN 60 (RP2350A)
U4: ESP-PSRAM32; SO-8
U5: W25Q128JVS; SOIC-8
USB1: USB4215-03-A; USB Type C
Y1: ASE-xxxMHz; Crystal (3225, active)

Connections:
+1V1: C10.1, C11.1, C12.1, C23.1, L2.1, U3.6 (DVDD), U3.23 (DVDD), U3.39 (DVDD), U3.50 (VREG_FB)
+3V3: C2.1, C13.1, C14.1, C15.1, C16.1, C17.1, C18.1, C19.1, C20.1, C22.1, C24.1, C25.1, C27.2, R2.2, R20.1, SD1.P4 (VDD), SD2.4 (VDD), U1.2 (VO), U3.1 (IOVDD), U3.11 (IOVDD), U3.20 (IOVDD), U3.30 (IOVDD), U3.38 (IOVDD), U3.44 (ADC_AVDD), U3.45 (IOVDD), U3.49 (VREG_VIN), U3.53 (USB_OTP_VDD), U3.54 (QSPI_IOVDD), U4.8 (VCC), U5.8 (VCC), Y1.1 (EN), Y1.4 (Vdd)
/A_OUTB: J1.5, R7.2, R8.2
/A_OUTL: J1.1, J1.8, R5.2
/A_OUTR: J1.3, J1.10, R9.2
/A_TDAL: J1.7, U2.6 (A_LEFT)
/A_TDAR: J1.9, U2.8 (A_RIGHT)
/Audio Out/L: AJ1.T, C3.2, R6.1
/Audio Out/R: AJ1.R, C5.2, R10.1
/D+: R19.1, R21.1, USB1.6 (DP1), USB1.8 (DP2)
/D-: R22.1, R23.1, USB1.5 (DN2), USB1.7 (DN1)
/GPIO0: D1.1 (K), R13.2, U3.2 (GPIO0)
/GPIO1: D2.1 (K), R14.2, U3.3 (GPIO1)
/GPIO2: D3.1 (K), R16.2, U3.4 (GPIO2)
/GPIO3: D4.1 (K), R17.2, U3.5 (GPIO3)
/GPIO4: SD1.P7 (DAT0), SD2.7 (DAT0), U3.7 (GPIO4)
/GPIO5: SD1.P2 (CD/DAT3), SD2.2 (DAT3/CD), U3.8 (GPIO5)
/GPIO6: SD1.P5 (CLK), SD2.5 (CLK), U3.9 (GPIO6)
/GPIO7: SD1.P3 (CMD), SD2.3 (CMD), U3.10 (GPIO7)
/GPIO8: U3.12 (GPIO8), U4.1 (~CE)
/GPIO9: J1.6, U2.3 (DATA), U3.13 (GPIO9)
/GPIO10: J1.4, U2.1 (SCLK), U3.14 (GPIO10)
/GPIO11: J1.2, U2.2 (LRCK), U3.15 (GPIO11)
/GPIO12: R27.2, U3.16 (GPIO12)
/GPIO13: R28.2, U3.17 (GPIO13)
/GPIO14: R29.2, U3.18 (GPIO14)
/GPIO15: R30.2, U3.19 (GPIO15)
/GPIO16: R31.2, U3.27 (GPIO16)
/GPIO17: R32.2, U3.28 (GPIO17)
/GPIO18: R33.2, U3.29 (GPIO18)
/GPIO19: R34.2, U3.31 (GPIO19)
/GPIO20: GP1.4, U3.32 (GPIO20)
/GPIO21: GP1.3, U3.33 (GPIO21)
/GPIO26: D5.1 (K), R35.1
/GPIO27: D6.1 (K), R36.1, U3.41 (GPIO27_ADC1)
/Gamepad/J1_DATA: GP1.2, R35.2
/Gamepad/J2_DATA: GP1.1, R36.2
/PS2/PS/2 CLK: MD1.5, R15.2, R16.1
/PS2/PS/2 DATA: MD1.1, R17.1, R18.2
/RP2350A/FLASH_SS: R25.2, U5.1 (~CS)
/RP2350A/QSPI_SCLK: U3.56 (QSPI_SCLK), U4.6 (SCLK), U5.6 (CLK)
/RP2350A/QSPI_SD0: U3.57 (QSPI_SD0), U4.5 (SI/SIO), U5.5 (DI(IO0))
/RP2350A/QSPI_SD1: U3.59 (QSPI_SD1), U4.2 (SO/SIO), U5.2 (DO(IO1))
/RP2350A/QSPI_SD2: U3.58 (QSPI_SD2), U4.3 (SIO2), U5.3 (IO2)
/RP2350A/QSPI_SD3: U3.55 (QSPI_SD3), U4.7 (SIO3), U5.7 (IO3)
/RP2350A/QSPI_SS: R24.1, R25.1, U3.60 (QSPI_SS)
/RP2350A/VREG_AVDD: C21.1, R20.2, U3.46 (VREG_AVDD)
/RP2350A/VREG_LX: L2.2, U3.48 (VREG_LX)
/RP2350A/XIN: U3.21 (XIN), Y1.3 (OUT)
/RP2350A/~USB_BOOT: R24.2, SW2.2
/RUN: SW1.1, U3.26 (RUN)
/SD Card/DAT1: SD1.P8 (DAT1), SD2.8 (DAT1)
/SD Card/DAT2: SD1.P1 (DAT2), SD2.1 (DAT2)
GND: AJ1.S, C1.2, C2.2, C4.2, C6.2, C7.2, C8.1, C9.2, C10.2, C11.2, C12.2, C13.2, C14.2, C15.2, C16.2, C17.2, C18.2, C19.2, C20.2, C21.2, C22.2, C23.2, C24.2, C25.2, C26.2, C27.1, C28.2, D1.2 (A), D2.2 (A), D3.2 (A), D4.2 (A), D5.2 (A), D6.2 (A), GP1.8, HDMI1.2 (G_D2), HDMI1.5 (G_D1), HDMI1.8 (G_D0), HDMI1.11 (G_CLK), HDMI1.17 (G_DDC/CEC), HDMI1.20 (SHIELD1), HDMI1.21 (SHIELD2), HDMI1.22 (SHIELD3), HDMI1.23 (SHIELD4), L1.1 (K), L3.1 (K), MD1.3, R1.1, R3.1, R4.2, R6.2, R10.2, SD1.G1 (GND_1), SD1.G2 (GND_2), SD1.G3 (GND_3), SD1.P6 (VSS), SD2.6 (VSS), SW1.2, SW2.1, U1.1 (GND), U2.4 (AGND), U3.47 (VREG_PGND), U3.61 (GND), U4.4 (VSS), U5.4 (GND), USB1.1 (GND), USB1.12 (GND), Y1.2 (GND)
GPIO25: R26.2, U3.37 (GPIO25)
unnamed: C3.1, C4.1, R5.1, R7.1
unnamed: C5.1, C6.1, R8.1, R9.1
unnamed: HDMI1.12 (CLKN), R27.1
unnamed: HDMI1.10 (CLKP), R28.1
unnamed: HDMI1.9 (D0N), R29.1
unnamed: HDMI1.7 (D0P), R30.1
unnamed: HDMI1.6 (D1N), R31.1
unnamed: HDMI1.4 (D1P), R32.1
unnamed: HDMI1.3 (D2N), R33.1
unnamed: HDMI1.1 (D2P), R34.1
unnamed: L1.2 (A), R2.1
unnamed: L3.2 (A), R26.1
unnamed: MD1.2, R11.2, R14.1
unnamed: MD1.6, R12.2, R13.1
unnamed: C7.1, U2.7 (FLT)
unnamed: R22.2, R23.2, U3.51 (USB_DM)
unnamed: R19.2, R21.2, U3.52 (USB_DP)
unnamed: R1.2, USB1.4 (CC1)
unnamed: R3.2, USB1.10 (CC2)
unnamed: R4.1, USB1.13 (SHIELD)
VBUS: C1.1, C8.2, C9.1, C26.1, C28.1, GP1.6, HDMI1.18 (+5V), MD1.4, R11.1, R12.1, R15.1, R18.1, U1.3 (VI), U2.5 (VA), USB1.2 (VBUS), USB1.11 (VBUS)

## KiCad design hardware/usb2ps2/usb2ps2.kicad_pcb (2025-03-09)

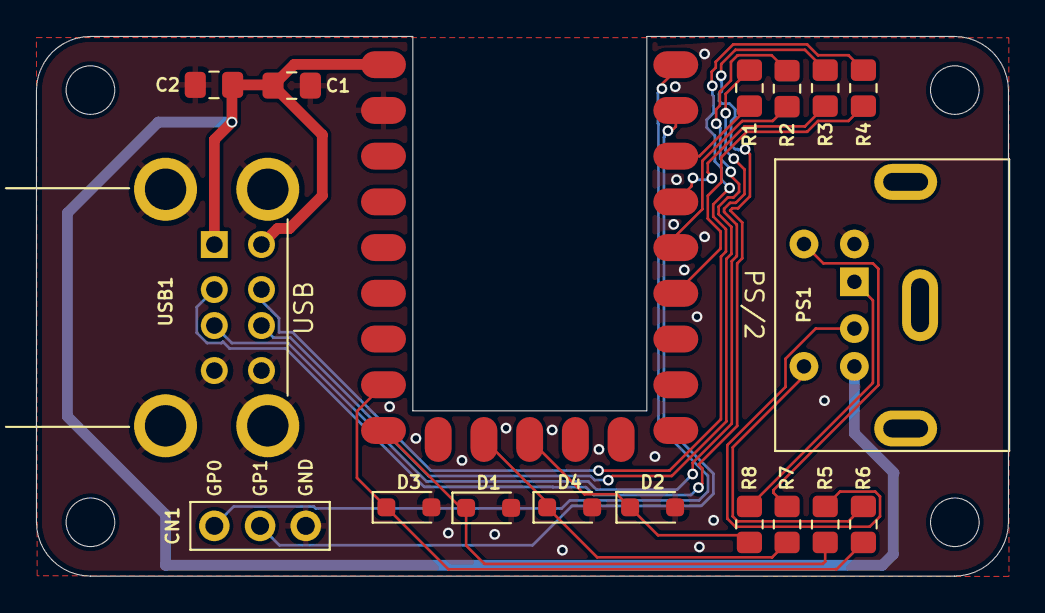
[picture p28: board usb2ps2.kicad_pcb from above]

Board: 2 copper layers, 54.0 x 30.0 mm, 22 parts (0 on the bottom side), 20 nets.

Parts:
C1, C2: 10u; Capacitor (0805)
CN1: UART; Pin Header (1x03)
D1, D2, D3, D4: 3V3; Diode (SOD-323)
H1, H2, H3, H4: MountingHole; Mounting Hole (2.7mm)
PS1: PS/2; MiniDIN (6 Pin, female)
R1, R2, R3, R4: 22R; Resistor (0805)
R5, R6, R7, R8: 100R; Resistor (0805)
RP1: RP 2040 Zero; Raspberry Pi Zero (on board)
USB1: USB_A_Stacked; USB Type A (stacked)

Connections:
/GPIO0: CN1.1, RP1.1 (0)
/GPIO1: CN1.2, RP1.2 (1)
/GPIO2: R1.1, RP1.3 (2)
/GPIO3: R3.1, RP1.4 (3)
/GPIO4: R2.1, RP1.5 (4)
/GPIO5: R4.1, RP1.6 (5)
/GPIO11: D2.1 (K), R8.2, RP1.12 (11)
/GPIO12: D4.1 (K), R7.2, RP1.13 (12)
/GPIO14: D1.1 (K), R5.2, RP1.15 (14)
/GPIO15: D3.1 (K), R6.2, RP1.16 (15)
/PS2 with Diodes/KB_CLK: PS1.5, R7.1
/PS2 with Diodes/KB_DATA: PS1.1, R8.1
/PS2 with Diodes/MS_CLK: PS1.6, R6.1
/PS2 with Diodes/MS_DATA: PS1.2, R5.1
GND: C1.2, C2.2, CN1.3, D1.2 (A), D2.2 (A), D3.2 (A), D4.2 (A), PS1.3, RP1.22 (GND), USB1.4 (GND1), USB1.8 (GND2), USB1.9 (Shield)
unnamed: R1.2, USB1.3 (D1+)
unnamed: R3.2, USB1.2 (D1-)
unnamed: R2.2, USB1.7 (D2+)
unnamed: R4.2, USB1.6 (D2-)
VBUS: C1.1, C2.1, PS1.4, RP1.23 (5V), USB1.1 (VBUS1), USB1.5 (VBUS2)

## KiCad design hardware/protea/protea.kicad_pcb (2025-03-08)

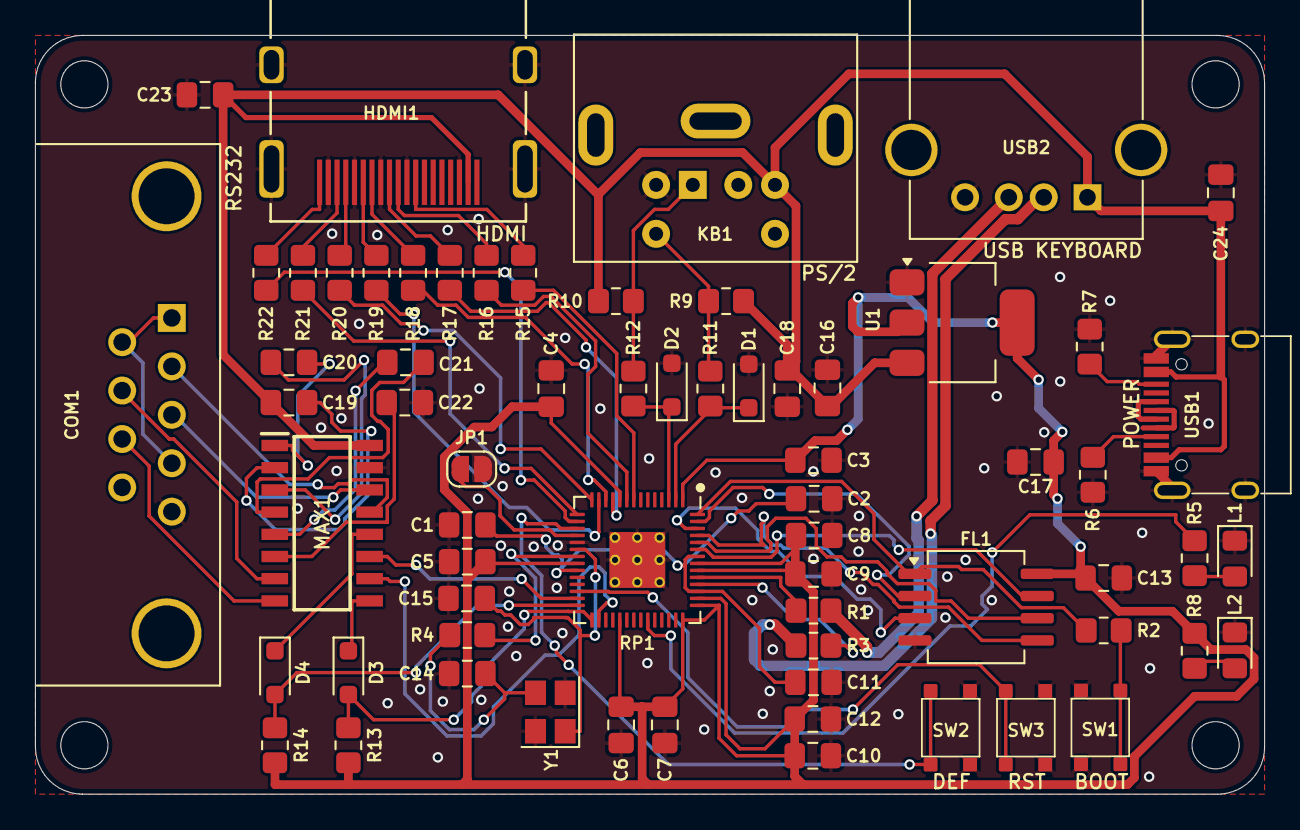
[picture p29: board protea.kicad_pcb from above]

Board: 2 copper layers, 70.3 x 43.4 mm, 70 parts (0 on the bottom side), 65 nets.

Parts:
C1, C2, C3, C4, C5, C6, C7, C8, C9, C10, C13, C18, C23: 100n; Capacitor (0805)
C11, C12, C19, C20, C21, C22: 1u; Capacitor (0805)
C14, C15: 15p; Capacitor (0805)
C16, C17, C24: 10u; Capacitor (0805)
COM1: D-SUB 9 Male; D-SUB (9 pin, male, top mount)
D1, D2: 3V3; Diode (SOD-323)
D3, D4: 1N4148; Diode (SOD-323)
FL1: W25Q128JVSIQ; SOIC-8
H1, H2, H3, H4: MountingHole; MountingHole_2.7mm
HDMI1: DC3RX19JA2; HDMI (female)
JP1: HDMI_DEF; Jumper (solder)
KB1: PS/2; MiniDIN (6 Pin, female)
L1: Blue; LED (0805)
L2: Green; LED (0805)
MAX1: MAX232CSE+; SOIC127P600X175-16N
R1, R3: 27R; Resistor (0805)
R2, R4, R5, R8, R9, R13, R14: 1K; Resistor (0805)
R6, R7: 5.1K; Resistor (0805)
R10: 1k; Resistor (0805)
R11, R12: 100R; Resistor (0805)
R15, R16, R17, R18, R19, R20, R21, R22: 270R; Resistor (0805)
RP1: RP2040; QFN 56
SW1: Flash Button; Button (SMD, 3x3mm)
SW2, SW3: KLS7-TS3302; Button (SMD, 3x3mm)
U1: NCP1117 3.3; SOT-223
USB1: USB4215; USB Type C
USB2: 676430910; USB Type A (single)
Y1: 12 MHz; Crystal (3225)

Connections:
+3V3: C3.1, C4.1, C5.1, C6.1, C7.1, C8.1, C9.1, C10.1, C12.1, C13.1, C17.1, FL1.8 (VCC), R8.2, R13.2, R14.2, RP1.1 (IOVDD), RP1.10 (IOVDD), RP1.22 (IOVDD), RP1.33 (IOVDD), RP1.42 (IOVDD), RP1.43 (ADC_AVDD), RP1.44 (VREG_IN), RP1.48 (USB_VDD), RP1.49 (IOVDD), U1.2 (VO)
/GPIO0: D1.1 (K), R11.2, RP1.2 (GPIO0)
/GPIO1: D2.1 (K), R12.2, RP1.3 (GPIO1)
/GPIO6: R15.2, RP1.8 (GPIO6)
/GPIO7: R16.2, RP1.9 (GPIO7)
/GPIO8: R17.2, RP1.11 (GPIO8)
/GPIO9: R18.2, RP1.12 (GPIO9)
/GPIO10: R19.2, RP1.13 (GPIO10)
/GPIO11: R20.2, RP1.14 (GPIO11)
/GPIO12: R21.2, RP1.15 (GPIO12)
/GPIO13: R22.2, RP1.16 (GPIO13)
/GPIO14: RP1.17 (GPIO14), SW2.3, SW2.4
/GPIO15: JP1.1 (A), RP1.18 (GPIO15)
/GPIO16: MAX1.11 (T1IN), RP1.27 (GPIO16)
/GPIO17: D4.2 (A), R14.1, RP1.28 (GPIO17)
/GPIO18: D3.2 (A), R13.1, RP1.29 (GPIO18)
/GPIO19: MAX1.10 (T2IN), RP1.30 (GPIO19)
/PD+: USB1.6 (DP1), USB1.8 (DP2)
/PD-: USB1.5 (DN2), USB1.7 (DN1)
/RD+: R1.1, USB2.3 (D+)
/RD-: R3.1, USB2.2 (D-)
/RP2040/GPIO25: R5.2, RP1.37 (GPIO25)
/RP2040/QSPI_SCLK: FL1.6 (CLK), RP1.52 (QSPI_SCLK)
/RP2040/QSPI_SD0: FL1.5 (DI(IO0)), RP1.53 (QSPI_SD0)
/RP2040/QSPI_SD1: FL1.2 (DO(IO1)), RP1.55 (QSPI_SD1)
/RP2040/QSPI_SD2: FL1.3 (IO2), RP1.54 (QSPI_SD2)
/RP2040/QSPI_SD3: FL1.7 (IO3), RP1.51 (QSPI_SD3)
/RP2040/QSPI_SS: FL1.1 (~CS), R2.1, RP1.56 (QSPI_SS)
/RP2040/XIN: C15.1, RP1.20 (XIN), Y1.1
/RP2040/XOUT: R4.1, RP1.21 (XOUT)
/RP2040/~USB_BOOT: R2.2, SW1.3, SW1.4
/RS232/C1+: C20.2, MAX1.1 (C1+)
/RS232/C1-: C20.1, MAX1.3 (C1-)
/RS232/C2+: C21.2, MAX1.4 (C2+)
/RS232/C2-: C21.1, MAX1.5 (C2-)
/RS232/CTS_IN: COM1.7, MAX1.7 (T2OUT)
/RS232/CTS_MAX: D3.1 (K), MAX1.9 (R2OUT)
/RS232/RTS_IN: COM1.8, MAX1.8 (R2IN)
/RS232/RX_IN: COM1.3, MAX1.14 (T1OUT)
/RS232/RX_MAX: D4.1 (K), MAX1.12 (R1OUT)
/RS232/TX_IN: COM1.2, MAX1.13 (R1IN)
/RS232/V+: C19.1, MAX1.2 (V+)
/RS232/V-: C22.1, MAX1.6 (V-)
/RUN: RP1.26 (RUN), SW3.3, SW3.4
GND: C1.2, C2.2, C3.2, C4.2, C5.2, C6.2, C7.2, C8.2, C9.2, C10.2, C11.2, C12.2, C13.2, C14.2, C15.2, C16.2, C17.2, C18.2, C22.2, C23.2, C24.1, COM1.5, D1.2 (A), D2.2 (A), FL1.4 (GND), HDMI1.2 (G_D2), HDMI1.5 (G_D1), HDMI1.8 (G_D0), HDMI1.11 (G_CLK), HDMI1.17 (G_DDC/CEC), HDMI1.20 (SHIELD1), HDMI1.21 (SHIELD2), HDMI1.22 (SHIELD3), HDMI1.23 (SHIELD4), JP1.2 (B), KB1.3, L1.1 (K), L2.1 (K), MAX1.15 (GND), R6.1, R7.1, RP1.19 (TESTEN), RP1.57 (GND), SW1.1, SW1.2, SW2.1, SW2.2, SW3.1, SW3.2, U1.1 (GND), USB1.1 (GND), USB1.12 (GND), USB1.13 (SHIELD), USB2.4 (GND), USB2.5 (Shield), Y1.2, Y1.4
unnamed: C14.1, R4.2, Y1.3
unnamed: COM1.1, COM1.4, COM1.6
unnamed: HDMI1.12 (CLKN), R15.1
unnamed: HDMI1.10 (CLKP), R16.1
unnamed: HDMI1.9 (D0N), R17.1
unnamed: HDMI1.7 (D0P), R18.1
unnamed: HDMI1.6 (D1N), R19.1
unnamed: HDMI1.4 (D1P), R20.1
unnamed: HDMI1.3 (D2N), R21.1
unnamed: HDMI1.1 (D2P), R22.1
unnamed: KB1.1, R10.2, R12.1
unnamed: KB1.5, R9.2, R11.1
unnamed: L1.2 (A), R5.1
unnamed: L2.2 (A), R8.1
unnamed: R3.2, RP1.46 (USB_DM)
unnamed: R1.2, RP1.47 (USB_DP)
unnamed: C1.1, C2.1, C11.1, RP1.23 (DVDD), RP1.45 (VREG_VOUT), RP1.50 (DVDD)
unnamed: R6.2, USB1.4 (CC1)
unnamed: R7.2, USB1.10 (CC2)
VBUS: C16.1, C18.1, C19.2, C23.1, C24.2, HDMI1.18 (+5V), KB1.4, MAX1.16 (VCC), R9.1, R10.1, U1.3 (VI), USB1.2 (VBUS), USB1.11 (VBUS), USB2.1 (VBUS)

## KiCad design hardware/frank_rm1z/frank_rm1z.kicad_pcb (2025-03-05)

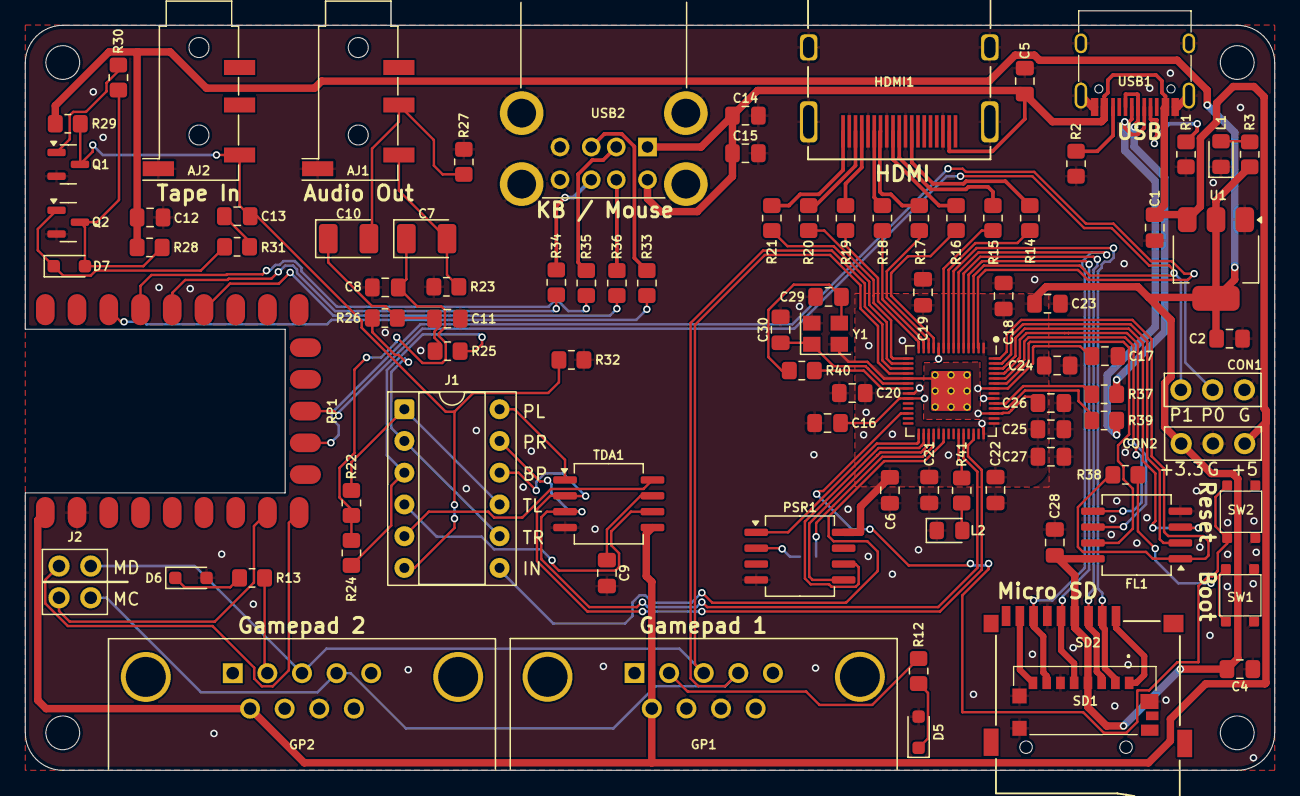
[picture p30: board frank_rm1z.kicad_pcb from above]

Board: 2 copper layers, 100.0 x 59.6 mm, 96 parts (1 on the bottom side), 88 nets.

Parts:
AJ1, AJ2: PJ-320D; Jack (3.5mm, PJ-320D)
C1, C2, C9, C14, C15: 10u; Capacitor (0805)
C4, C5, C6, C12, C13, C16, C17, C18, C19, C20, C21, C22, C23, C24, C25, C28: 100n; Capacitor (0805)
C7, C10: 10u; Capacitor (3528, tantalum, polar)
C8, C11: 10n; Capacitor (0805)
C26, C27: 1u; Capacitor (0805)
C29, C30: 15p; Capacitor (0805)
CON1, CON2: Pin Header 1x03; Pin Header (1x03)
D5, D6: 3V3; Diode (SOD-323)
D7: 1N4148; Diode (SOD-323)
FL1: W25Q128JVSIQ; SOIC-8
GP1, GP2: D-SUB 9 Male; D-SUB (9 pin, male, top mount)
H1, H2, H3, H4: Hole 2.7mm; Mounting Hole (2.7mm)
HDMI1: DC3RX19JA2; HDMI (female)
J1: Pin Header 2x18; DIP Switch (6x6)
J2: Pin Header 2x18; Pin Header (2x02)
JP1: Jumper (Solder); Jumper (solder)
L1: Green; LED (0805)
L2: BLUE; LED (0805)
PSR1: ESP-PSRAM32; SOIC-8
Q1, Q2: BC850; SOT-23
R1, R2: 5.1K; Resistor (0805)
R3, R12, R13, R22, R26, R29, R38, R40, R41: 1K; Resistor (0805)
R14, R15, R16, R17, R18, R19, R20, R21: 270R; Resistor (0805)
R23, R27: 330R; Resistor (0805)
R24, R25: 2K; Resistor (0805)
R28, R30, R31: 10K; Resistor (0805)
R32: 100R; Resistor (0805)
R33, R34, R35, R36: 22R; Resistor (0805)
R37, R39: 27R; Resistor (0805)
RP1: RP2040-Zero; Raspberry Pi Zero (on board)
RP2: RP2040; QFN 56
SD1: 0475710001; MicroSD (SMD, short)
SD2: 104031-0811; MicroSD (SMD, long)
SW1, SW2: SW_Push; Button (SMD, 3x3mm, 1-1)
TDA1: TDA1387T; SOIC-8
U1: NCP1117 3.3; SOT-223
USB1: USB4215; USB Type C
USB2: SS-52100-004; USB Type A (stacked)
Y1: 12 MHz; Crystal (3225)

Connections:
+3V3: C2.1, C4.2, C6.1, C12.1, C18.1, C19.1, C20.1, C21.1, C22.1, C23.1, C24.1, C25.1, C27.1, C28.1, CON2.1, FL1.8 (VCC), PSR1.8 (VCC), R3.2, R28.1, R29.1, RP2.1 (IOVDD), RP2.10 (IOVDD), RP2.22 (IOVDD), RP2.33 (IOVDD), RP2.42 (IOVDD), RP2.43 (ADC_AVDD), RP2.44 (VREG_IN), RP2.48 (USB_VDD), RP2.49 (IOVDD), SD1.P4 (VDD), SD2.4 (VDD), U1.2 (VO)
/A_OUTB: J1.5, R24.2, R25.2
/A_OUTL: J1.1, J1.8, R22.2
/A_OUTR: J1.3, J1.10, R26.2
/A_TDAL: J1.7, TDA1.6 (A_LEFT)
/A_TDAR: J1.9, TDA1.8 (A_RIGHT)
/Audio Out/L: AJ1.T, C7.2, R23.1
/Audio Out/R: AJ1.R, C10.2, R27.1
/D+: R37.1, USB1.6 (DP1), USB1.8 (DP2)
/D-: R39.1, USB1.5 (DN2), USB1.7 (DN1)
/DAT1: SD1.P8 (DAT1), SD2.8 (DAT1)
/DAT2: SD1.P1 (DAT2), SD2.1 (DAT2)
/GP1_DATA: D5.1 (K), R12.1
/GP2_DATA: D6.1 (K), R13.1
/GPIO0: CON1.2, RP1.13 (12), RP2.2 (GPIO0)
/GPIO1: CON1.3, RP1.12 (11), RP2.3 (GPIO1)
/GPIO2: RP2.4 (GPIO2), SD1.P5 (CLK), SD2.5 (CLK)
/GPIO3: RP2.5 (GPIO3), SD1.P3 (CMD), SD2.3 (CMD)
/GPIO4: RP2.6 (GPIO4), SD1.P7 (DAT0), SD2.7 (DAT0)
/GPIO5: RP2.7 (GPIO5), SD1.P2 (CD/DAT3), SD2.2 (DAT3/CD)
/GPIO6: R14.2, RP2.8 (GPIO6)
/GPIO7: R15.2, RP2.9 (GPIO7)
/GPIO8: R16.2, RP2.11 (GPIO8)
/GPIO9: R17.2, RP2.12 (GPIO9)
/GPIO10: R18.2, RP2.13 (GPIO10)
/GPIO11: R19.2, RP2.14 (GPIO11)
/GPIO12: R20.2, RP2.15 (GPIO12)
/GPIO13: R21.2, RP2.16 (GPIO13)
/GPIO14: GP1.4, GP2.4, J2.4, RP2.17 (GPIO14)
/GPIO15: GP1.3, GP2.3, J2.2, RP2.18 (GPIO15)
/GPIO18: PSR1.1 (~CE), RP2.29 (GPIO18)
/GPIO19: PSR1.6 (SCLK), RP2.30 (GPIO19)
/GPIO20: PSR1.5 (SI/SIO), RP2.31 (GPIO20)
/GPIO21: JP1.2 (B), RP2.32 (GPIO21)
/GPIO22: J1.12, RP2.34 (GPIO22)
/GPIO26: J1.4, RP2.38 (GPIO26_ADC0), TDA1.3 (DATA)
/GPIO27: J1.2, TDA1.1 (SCLK)
/GPIO28: J1.6, RP2.40 (GPIO28_ADC2), TDA1.2 (LRCK)
/LOAD_IN_D: AJ2.T, C13.1, J1.11, Q1.3 (C), R29.2, R32.1
/MS_CLK: J2.3, RP1.16 (15)
/MS_DATA: J2.1, RP1.15 (14)
/RP2040/GPIO25: R41.2, RP2.37 (GPIO25)
/RP2040/QSPI_SCLK: FL1.6 (CLK), RP2.52 (QSPI_SCLK)
/RP2040/QSPI_SD0: FL1.5 (DI(IO0)), RP2.53 (QSPI_SD0)
/RP2040/QSPI_SD1: FL1.2 (DO(IO1)), RP2.55 (QSPI_SD1)
/RP2040/QSPI_SD2: FL1.3 (IO2), RP2.54 (QSPI_SD2)
/RP2040/QSPI_SD3: FL1.7 (IO3), RP2.51 (QSPI_SD3)
/RP2040/QSPI_SS: FL1.1 (~CS), R38.1, RP2.56 (QSPI_SS)
/RP2040/RUN: RP2.26 (RUN), SW2.1
/RP2040/XIN: C30.1, RP2.20 (XIN), Y1.1
/RP2040/XOUT: R40.1, RP2.21 (XOUT)
/RP2040/~USB_BOOT: R38.2, SW1.2
/USB_D1M: R35.1, RP1.4 (3)
/USB_D1P: R33.1, RP1.3 (2)
/USB_D2M: R36.1, RP1.6 (5)
/USB_D2P: R34.1, RP1.5 (4)
GND: AJ1.S, AJ2.S, C1.2, C2.2, C4.1, C5.2, C6.2, C8.2, C9.2, C11.2, C12.2, C14.2, C15.2, C16.2, C17.2, C18.2, C19.2, C20.2, C21.2, C22.2, C23.2, C24.2, C25.2, C26.2, C27.2, C28.2, C29.2, C30.2, CON1.1, CON2.2, D5.2 (A), D6.2 (A), FL1.4 (GND), GP1.8, GP2.8, HDMI1.2 (G_D2), HDMI1.5 (G_D1), HDMI1.8 (G_D0), HDMI1.11 (G_CLK), HDMI1.17 (G_DDC/CEC), HDMI1.20 (SHIELD1), HDMI1.21 (SHIELD2), HDMI1.22 (SHIELD3), HDMI1.23 (SHIELD4), L1.1 (K), L2.1 (K), PSR1.4 (VSS), Q1.2 (E), Q2.2 (E), R1.1, R2.1, R23.2, R27.2, R32.2, RP1.22 (GND), RP2.19 (TESTEN), RP2.57 (GND), SD1.G1 (GND_1), SD1.G2 (GND_2), SD1.G3 (GND_3), SD1.P6 (VSS), SD2.6 (VSS), SW1.1, SW2.2, TDA1.4 (AGND), U1.1 (GND), USB1.1 (GND), USB1.12 (GND), USB1.13 (SHIELD), USB2.4 (GND1), USB2.8 (GND2), USB2.9 (Shield), Y1.2, Y1.4
unnamed: C7.1, C8.1, R22.1, R24.1
unnamed: C10.1, C11.1, R25.1, R26.1
unnamed: C13.2, R31.1
unnamed: C29.1, R40.2, Y1.3
unnamed: D7.2 (A), Q2.3 (C), R28.2, R30.1
unnamed: D7.1 (K), Q2.1 (B), R31.2
unnamed: GP1.2, R12.2
unnamed: GP2.2, R13.2
unnamed: HDMI1.12 (CLKN), R14.1
unnamed: HDMI1.10 (CLKP), R15.1
unnamed: HDMI1.9 (D0N), R16.1
unnamed: HDMI1.7 (D0P), R17.1
unnamed: HDMI1.6 (D1N), R18.1
unnamed: HDMI1.4 (D1P), R19.1
unnamed: HDMI1.3 (D2N), R20.1
unnamed: HDMI1.1 (D2P), R21.1
unnamed: JP1.1 (A), PSR1.2 (SO/SIO)
unnamed: L1.2 (A), R3.1
unnamed: L2.2 (A), R41.1
unnamed: Q1.1 (B), R30.2
unnamed: R39.2, RP2.46 (USB_DM)
unnamed: R37.2, RP2.47 (USB_DP)
unnamed: C16.1, C17.1, C26.1, RP2.23 (DVDD), RP2.45 (VREG_VOUT), RP2.50 (DVDD)
unnamed: C9.1, TDA1.7 (FLT)
unnamed: R1.2, USB1.4 (CC1)
unnamed: R2.2, USB1.10 (CC2)
unnamed: R33.2, USB2.3 (D1+)
unnamed: R35.2, USB2.2 (D1-)
unnamed: R34.2, USB2.7 (D2+)
unnamed: R36.2, USB2.6 (D2-)
VBUS: C1.1, C5.1, C14.1, C15.1, CON2.3, GP1.6, GP2.6, HDMI1.18 (+5V), RP1.23 (5V), TDA1.5 (VA), U1.3 (VI), USB1.2 (VBUS), USB1.11 (VBUS), USB2.1 (VBUS1), USB2.5 (VBUS2)

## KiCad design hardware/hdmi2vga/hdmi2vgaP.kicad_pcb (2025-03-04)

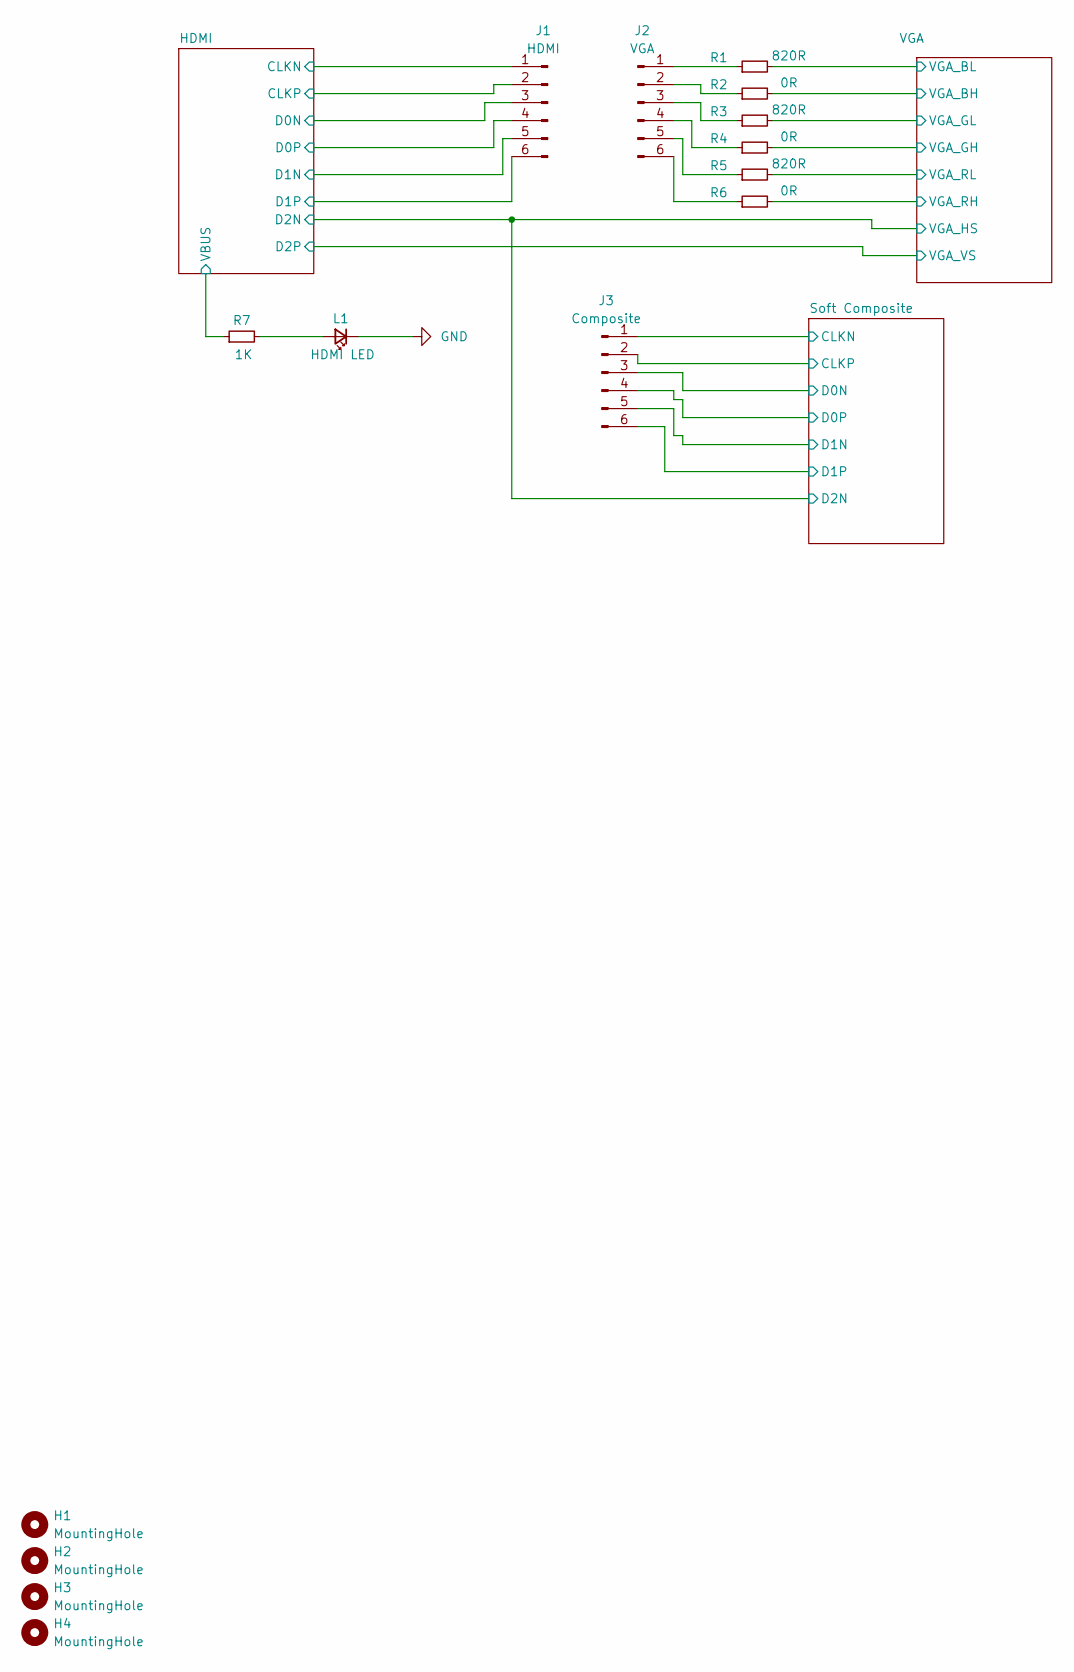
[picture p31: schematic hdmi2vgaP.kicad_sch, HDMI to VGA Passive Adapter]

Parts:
H1, H2, H3, H4: MountingHole; Mounting Hole (2.7mm)
J1: HDMI; Pin Header (1x06)
J2: VGA; Pin Header (1x06)
J3: Composite; Pin Header (1x06)
L1: HDMI LED; LED (0805)
R1, R3, R5: 820R; Resistor (0805)
R2, R4, R6: 0R; Resistor (0805)
R7: 1K; Resistor (0805)

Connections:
/HDMI/CLKN: J1.1; also elsewhere on the board
/HDMI/CLKP: J1.2; also elsewhere on the board
/HDMI/D0N: J1.3; also elsewhere on the board
/HDMI/D0P: J1.4; also elsewhere on the board
/HDMI/D1N: J1.5; also elsewhere on the board
/HDMI/D1P: J1.6; also elsewhere on the board
/HDMI/VBUS: R7.1; also elsewhere on the board
/Soft Composite/CLKN: J3.1; also elsewhere on the board
/Soft Composite/CLKP: J3.2; also elsewhere on the board
/Soft Composite/D0N: J3.3; also elsewhere on the board
/Soft Composite/D0P: J3.4; also elsewhere on the board
/Soft Composite/D1N: J3.5; also elsewhere on the board
/Soft Composite/D1P: J3.6; also elsewhere on the board
/VGA/VGA_BH: R1.2, R2.2; also elsewhere on the board
/VGA/VGA_GH: R3.2, R4.2; also elsewhere on the board
/VGA/VGA_RH: R5.2, R6.2; also elsewhere on the board
GND: L1.1 (K); also elsewhere on the board
unnamed: J2.1, R1.1
unnamed: J2.2, R2.1
unnamed: J2.3, R3.1
unnamed: J2.4, R4.1
unnamed: J2.5, R5.1
unnamed: J2.6, R6.1
unnamed: L1.2 (A), R7.2

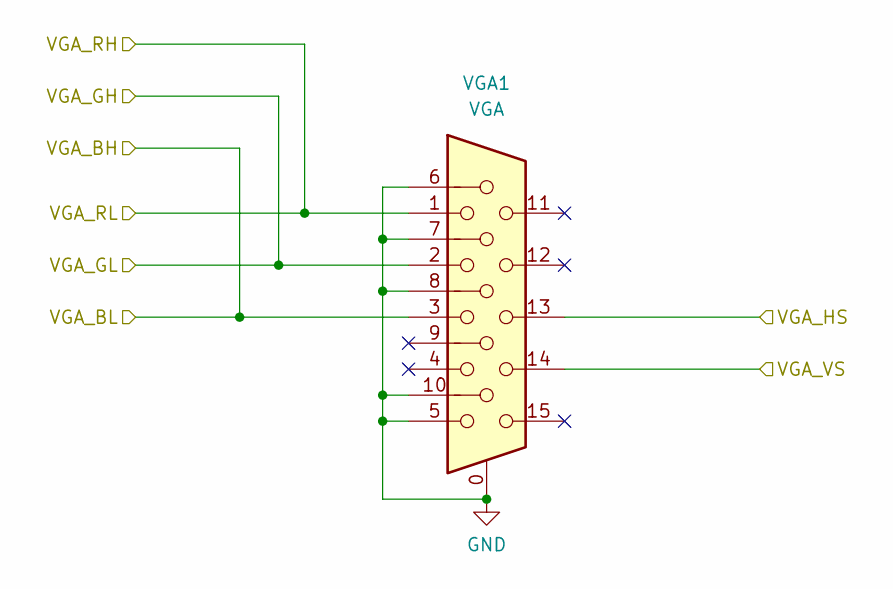
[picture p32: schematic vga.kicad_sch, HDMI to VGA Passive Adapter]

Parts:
VGA1: VGA; D-SUB (15 pin, female)

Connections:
/HDMI/D2N: VGA1.13; also elsewhere on the board
/HDMI/D2P: VGA1.14; also elsewhere on the board
/VGA/VGA_BH: VGA1.3; also elsewhere on the board
/VGA/VGA_GH: VGA1.2; also elsewhere on the board
/VGA/VGA_RH: VGA1.1; also elsewhere on the board
GND: VGA1.0, VGA1.5, VGA1.6, VGA1.7, VGA1.8, VGA1.10; also elsewhere on the board

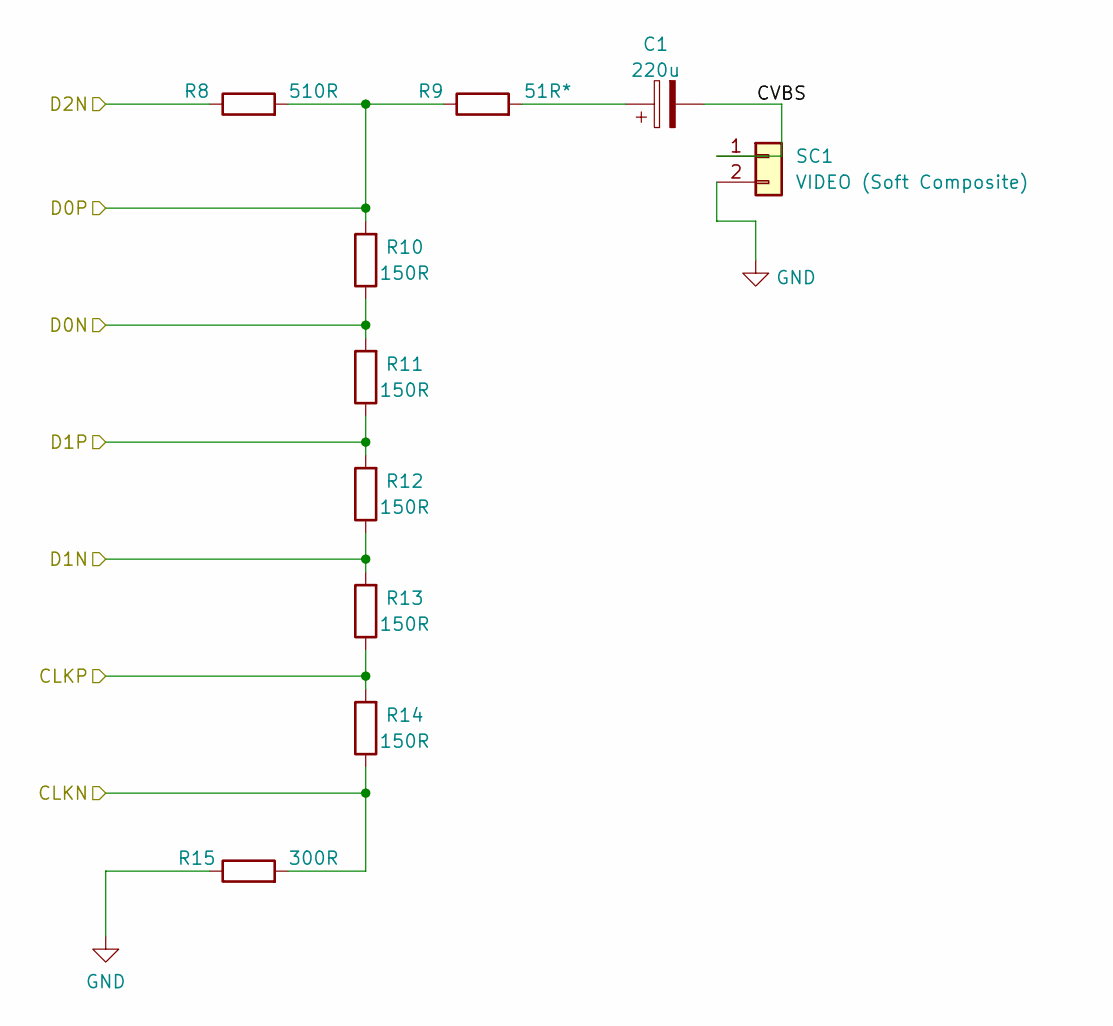
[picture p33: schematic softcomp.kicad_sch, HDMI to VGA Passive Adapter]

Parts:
C1: 220u; Capacitor (3528, tantalum, polar)
R8: 510R; Resistor (0805)
R9: 51R*; Resistor (0805)
R10, R11, R12, R13, R14: 150R; Resistor (0805)
R15: 300R; Resistor (0805)
SC1: VIDEO (Soft Composite); RCA

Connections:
/HDMI/D2N: R8.1; also elsewhere on the board
/Soft Composite/CLKN: R14.1, R15.2; also elsewhere on the board
/Soft Composite/CLKP: R13.1, R14.2; also elsewhere on the board
/Soft Composite/CVBS: C1.2, SC1.1
/Soft Composite/D0N: R10.1, R11.2; also elsewhere on the board
/Soft Composite/D0P: R8.2, R9.1, R10.2; also elsewhere on the board
/Soft Composite/D1N: R12.1, R13.2; also elsewhere on the board
/Soft Composite/D1P: R11.1, R12.2; also elsewhere on the board
GND: R15.1, SC1.2; also elsewhere on the board
unnamed: C1.1, R9.2

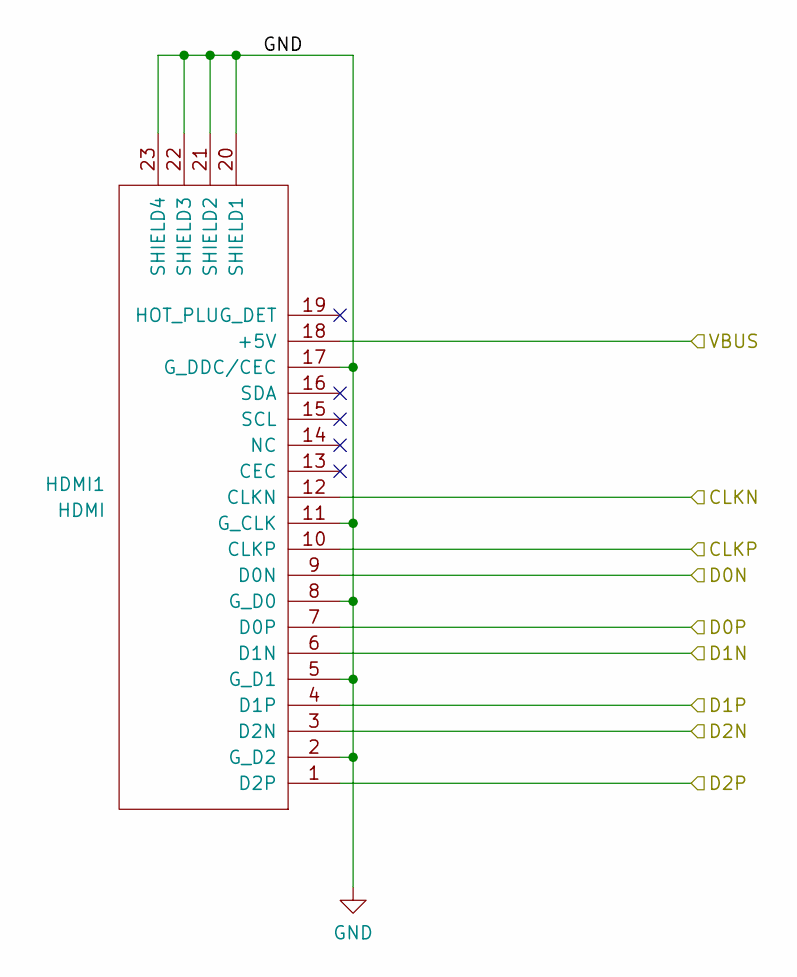
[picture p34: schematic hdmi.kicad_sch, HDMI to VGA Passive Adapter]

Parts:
HDMI1: HDMI; HDMI (male)

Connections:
/HDMI/CLKN: HDMI1.12 (CLKN); also elsewhere on the board
/HDMI/CLKP: HDMI1.10 (CLKP); also elsewhere on the board
/HDMI/D0N: HDMI1.9 (D0N); also elsewhere on the board
/HDMI/D0P: HDMI1.7 (D0P); also elsewhere on the board
/HDMI/D1N: HDMI1.6 (D1N); also elsewhere on the board
/HDMI/D1P: HDMI1.4 (D1P); also elsewhere on the board
/HDMI/D2N: HDMI1.3 (D2N); also elsewhere on the board
/HDMI/D2P: HDMI1.1 (D2P); also elsewhere on the board
/HDMI/VBUS: HDMI1.18 (+5V); also elsewhere on the board
GND: HDMI1.2 (G_D2), HDMI1.5 (G_D1), HDMI1.8 (G_D0), HDMI1.11 (G_CLK), HDMI1.17 (G_DDC/CEC), HDMI1.20 (SHIELD1), HDMI1.21 (SHIELD2), HDMI1.22 (SHIELD3), HDMI1.23 (SHIELD4); also elsewhere on the board

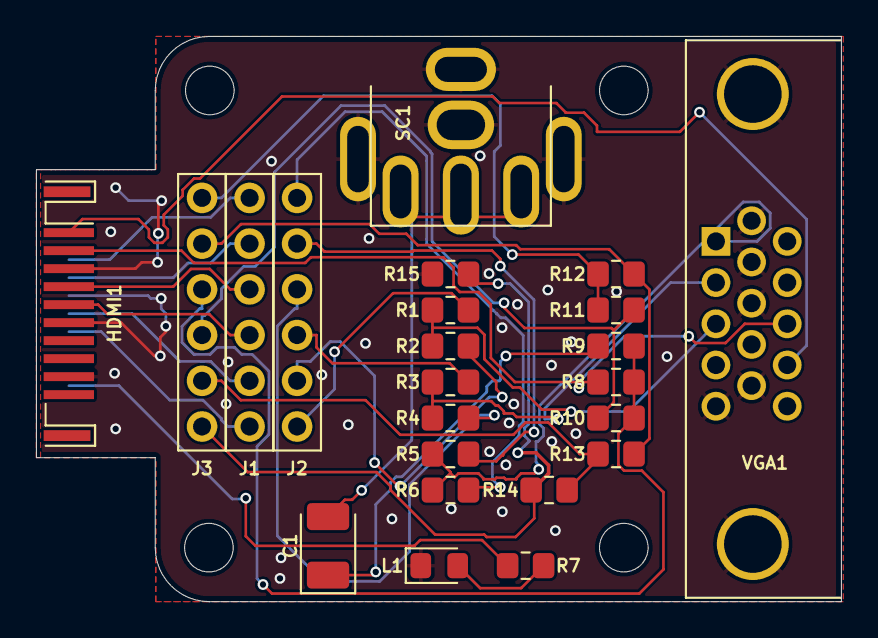
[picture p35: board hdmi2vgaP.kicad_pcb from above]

Board: 2 copper layers, 44.7 x 31.4 mm, 27 parts (0 on the bottom side), 28 nets.

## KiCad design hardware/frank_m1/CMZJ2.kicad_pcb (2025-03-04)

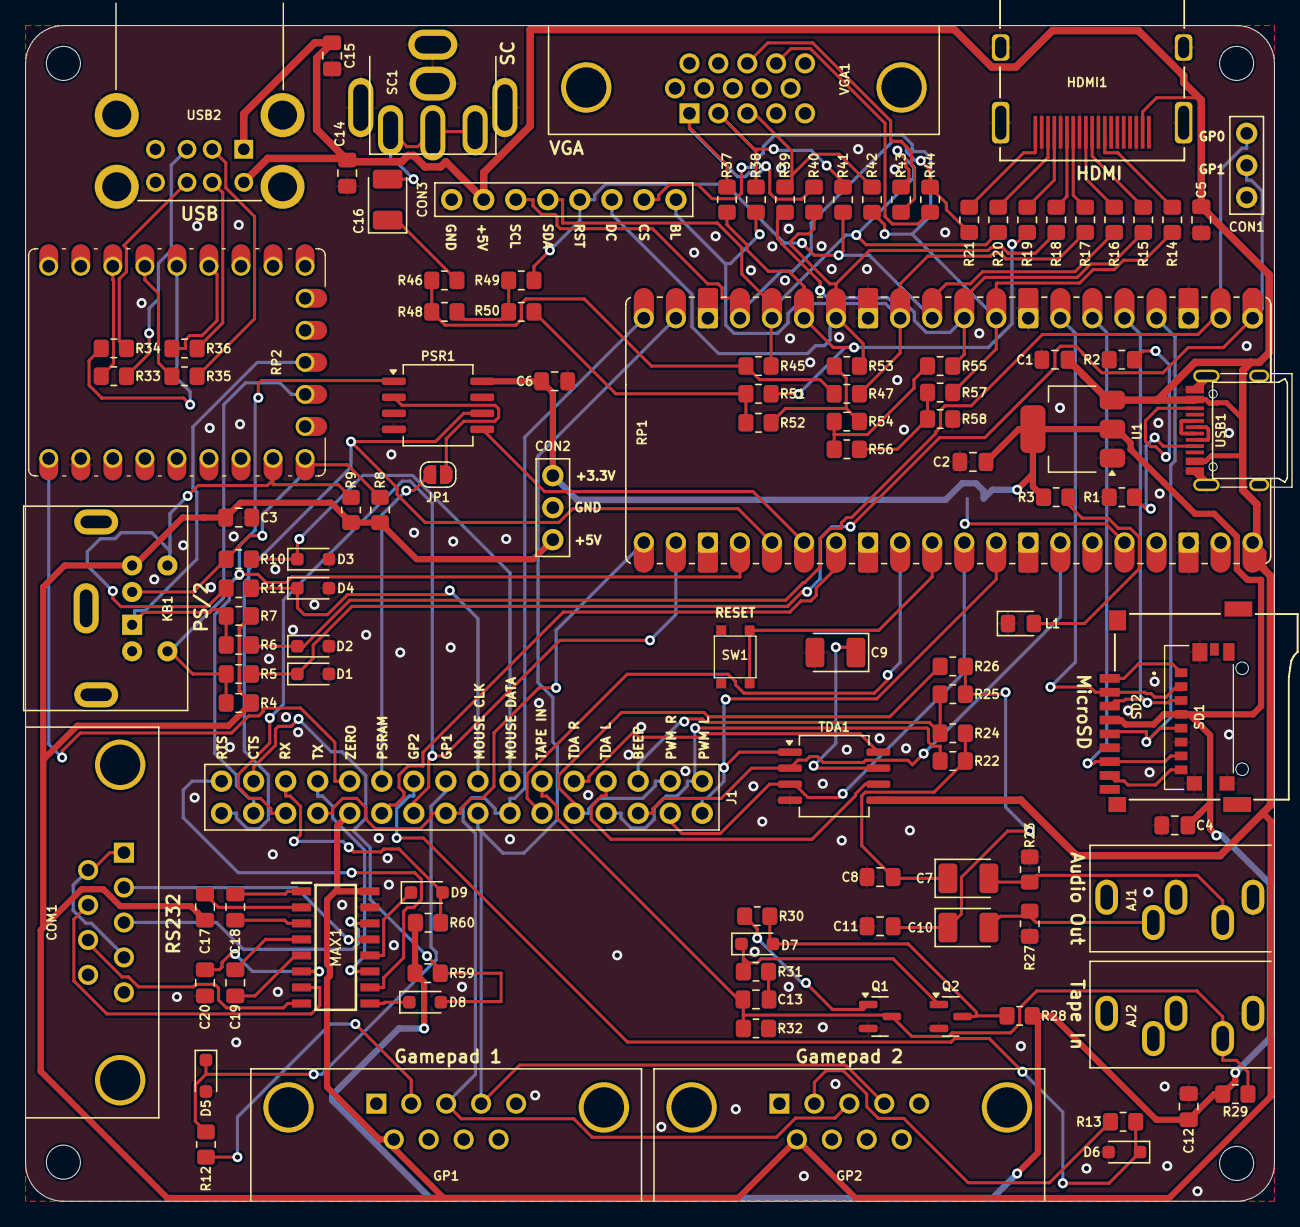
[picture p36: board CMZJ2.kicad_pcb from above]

Board: 2 copper layers, 99.0 x 93.2 mm, 122 parts (1 on the bottom side), 112 nets.

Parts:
AJ1, AJ2: SJ1-353XNG; Jack (3.5mm)
C1, C2, C14, C15: 10u; Capacitor (0805)
C3, C4, C5, C6, C12, C13: 100n; Capacitor (0805)
C7, C9, C10: 10u; Capacitor (3528, tantalum, polar)
C8, C11: 10n; Capacitor (0805)
C16: 220u; Capacitor (3528, tantalum, polar)
C17, C18, C19, C20: 1u; Capacitor (0805)
COM1: D-SUB 9 Male; D-SUB (9 pin, male, top mount)
CON1, CON2: Pin Header 1x03; Pin Header (1x03)
CON3: Pin Header 1x08; Pin Header (1x08)
D1, D2, D3, D4, D5, D6: 3V3; Diode (SOD-323)
D7, D8, D9: 1N4148; Diode (SOD-323)
GP1, GP2: D-SUB 9 Male; D-SUB (9 pin, male, top mount)
H1, H2, H3, H4: Hole 2.7mm; Mounting Hole (2.7mm)
HDMI1: DC3RX19JA2; HDMI (female)
J1: Pin Header 2x18; Pin Header (2x16)
JP1, JP2: Jumper (Solder); Jumper (solder)
KB1: MDC-036; MiniDIN (6 Pin, female)
L1: Green; LED (0805)
MAX1: MAX232CSE+; SOIC127P600X175-16N
PSR1: ESP-PSRAM32; SOIC-8
Q1, Q2: BC850; SOT-23
R1, R2: 5.1K; Resistor (0805)
R3, R4, R7, R8, R9, R12, R13, R22, R26, R29, R40, R41, R42, R59, R60: 1K; Resistor (0805)
R5, R6, R10, R11, R32, R43, R44: 100R; Resistor (0805)
R14, R15, R16, R17, R18, R19, R20, R21, R47, R49, R51, R53, R55, R57: 270R; Resistor (0805)
R23, R27, R37, R38, R39: 330R; Resistor (0805)
R24, R25: 2K; Resistor (0805)
R28, R30, R31: 10K; Resistor (0805)
R33, R34, R35, R36: 22R; Resistor (0805)
R45: 750R; Resistor (0805)
R46: 51R; Resistor (0805)
R48, R50, R52, R54, R56: 150R; Resistor (0805)
R58: 300R; Resistor (0805)
RP1: Rasberry Pi Pico; Raspberry Pi Pico
RP2: RP2040-Zero; Raspberry Pi Zero
SC1: RCA-103; RCA
SD1: 0475710001; MicroSD (SMD, short)
SD2: 104031-0811; MicroSD (SMD, long)
SW1: KLS7-TS3302; Button (SMD, 3x3mm)
TDA1: TDA1387T; SOIC-8
U1: NCP1117 3.3; SOT-223
USB1: USB4215; USB Type C
USB2: SS-52100-004; USB Type A (stacked)
VGA1: D-SUB 15 Female; D-SUB (15 pin, female)

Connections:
+3V3: C2.1, C4.2, C6.1, C12.1, CON2.1, JP2.2 (B), PSR1.8 (VCC), R3.2, R28.1, R29.1, R59.2, R60.2, SD1.P4 (VDD), SD2.4 (VDD), U1.2 (VO)
/A_OUTB: J1.5, R24.2, R25.2
/A_OUTL: J1.1, J1.8, R22.2
/A_OUTR: J1.3, J1.10, R26.2
/A_TDAL: J1.7, TDA1.6 (A_LEFT)
/A_TDAR: J1.9, TDA1.8 (A_RIGHT)
/Audio Out/L: AJ1.T, C7.2, R23.1
/Audio Out/R: AJ1.R, C10.2, R27.1
/Composite/CVBS: C16.2, SC1.1
/GP1_DATA: D5.1 (K), J1.17, R12.1
/GP2_DATA: D6.1 (K), J1.19, R13.1
/GPIO0: CON1.2, D1.1 (K), R5.2, RP1.1 (GPIO0)
/GPIO1: CON1.3, D2.1 (K), R6.2, RP1.2 (GPIO1)
/GPIO2: RP1.4 (GPIO2), SD1.P5 (CLK), SD2.5 (CLK)
/GPIO3: RP1.5 (GPIO3), SD1.P3 (CMD), SD2.3 (CMD)
/GPIO4: RP1.6 (GPIO4), SD1.P7 (DAT0), SD2.7 (DAT0)
/GPIO5: RP1.7 (GPIO5), SD1.P2 (CD/DAT3), SD2.2 (DAT3/CD)
/GPIO6: CON3.7, R14.2, R42.1, R57.1, RP1.9 (GPIO6)
/GPIO7: R15.2, R39.1, R55.1, RP1.10 (GPIO7)
/GPIO8: CON3.5, R16.2, R41.1, R49.1, RP1.11 (GPIO8)
/GPIO9: CON3.8, R17.2, R38.1, R47.1, RP1.12 (GPIO9)
/GPIO10: CON3.6, R18.2, R40.1, R53.1, RP1.14 (GPIO10)
/GPIO11: R19.2, R37.1, R51.1, RP1.15 (GPIO11)
/GPIO12: CON3.4, R20.2, R43.2, R45.1, RP1.16 (GPIO12)
/GPIO13: CON3.3, R21.2, R44.2, RP1.17 (GPIO13)
/GPIO14: GP1.4, GP2.4, J1.16, RP1.19 (GPIO14)
/GPIO15: GP1.3, GP2.3, J1.14, RP1.20 (GPIO15)
/GPIO16: J1.18, J1.26, RP1.21 (GPIO16)
/GPIO17: J1.20, J1.28, RP1.22 (GPIO17)
/GPIO18: J1.30, PSR1.1 (~CE), RP1.24 (GPIO18)
/GPIO19: J1.32, PSR1.6 (SCLK), RP1.25 (GPIO19)
/GPIO20: PSR1.5 (SI/SIO), RP1.26 (GPIO20)
/GPIO21: J1.22, RP1.27 (GPIO21)
/GPIO22: J1.12, RP1.29 (GPIO22)
/GPIO26: J1.4, RP1.31 (GPIO26_ADC0), TDA1.3 (DATA)
/GPIO27: J1.2, RP1.32 (GPIO27_ADC1), TDA1.1 (SCLK)
/GPIO28: J1.6, RP1.34 (GPIO28_ADC2), TDA1.2 (LRCK)
/KB_CLK: KB1.5, R4.2, R5.1, RP2.13 (12)
/KB_DATA: KB1.1, R6.1, R7.2, RP2.12 (11)
/LOAD_IN_D: AJ2.T, C13.1, J1.11, Q1.3 (C), R29.2, R32.1
/MS_CLK: KB1.6, R9.2, R11.1, RP2.16 (15)
/MS_CLK_3V: D4.1 (K), J1.15, R11.2
/MS_DATA: KB1.2, R8.2, R10.1, RP2.15 (14)
/MS_DATA_3V: D3.1 (K), J1.13, R10.2
/Micro SD/DAT1: SD1.P8 (DAT1), SD2.8 (DAT1)
/Micro SD/DAT2: SD1.P1 (DAT2), SD2.1 (DAT2)
/PSR_SOSIO: J1.21, JP1.2 (B)
/Power/D+: USB1.6 (DP1), USB1.8 (DP2)
/Power/D-: USB1.5 (DN2), USB1.7 (DN1)
/RS232/C1+: C18.2, MAX1.1 (C1+)
/RS232/C1-: C18.1, MAX1.3 (C1-)
/RS232/C2+: C19.2, MAX1.4 (C2+)
/RS232/C2-: C19.1, MAX1.5 (C2-)
/RS232/CTS_IN: COM1.7, MAX1.7 (T2OUT)
/RS232/CTS_MAX: D8.1 (K), MAX1.9 (R2OUT)
/RS232/RTS_IN: COM1.8, MAX1.8 (R2IN)
/RS232/RX_IN: COM1.3, MAX1.14 (T1OUT)
/RS232/RX_MAX: D9.1 (K), MAX1.12 (R1OUT)
/RS232/TX_IN: COM1.2, MAX1.13 (R1IN)
/RS232/V+: C17.1, MAX1.2 (V+)
/RS232/V-: C20.1, MAX1.6 (V-)
/RS232_CTS: D8.2 (A), J1.29, R59.1
/RS232_RTS: J1.31, MAX1.10 (T2IN)
/RS232_RX: D9.2 (A), J1.27, R60.1
/RS232_TX: J1.25, MAX1.11 (T1IN)
/RUN: RP1.30 (RUN), SW1.3, SW1.4
/USB_D1M: R35.1, RP2.4 (3)
/USB_D1P: R33.1, RP2.3 (2)
/USB_D2M: R36.1, RP2.6 (5)
/USB_D2P: R34.1, RP2.5 (4)
/ZERO_VBUS: J1.23, RP2.23 (5V)
GND: AJ1.S, AJ2.S, C1.2, C2.2, C3.2, C4.1, C5.2, C6.2, C8.2, C9.2, C11.2, C12.2, C14.2, C15.2, C20.2, COM1.5, CON1.1, CON2.2, CON3.1, D1.2 (A), D2.2 (A), D3.2 (A), D4.2 (A), D5.2 (A), D6.2 (A), GP1.8, GP2.8, HDMI1.2 (G_D2), HDMI1.5 (G_D1), HDMI1.8 (G_D0), HDMI1.11 (G_CLK), HDMI1.17 (G_DDC/CEC), HDMI1.20 (SHIELD1), HDMI1.21 (SHIELD2), HDMI1.22 (SHIELD3), HDMI1.23 (SHIELD4), KB1.3, L1.1 (K), MAX1.15 (GND), PSR1.4 (VSS), Q1.2 (E), Q2.2 (E), R1.1, R2.1, R23.2, R27.2, R32.2, R58.1, RP1.3 (GND), RP1.8 (GND), RP1.13 (GND), RP1.18 (GND), RP1.23 (GND), RP1.28 (GND), RP1.33 (AGND), RP1.38 (GND), RP2.22 (GND), SC1.2, SD1.G1 (GND_1), SD1.G2 (GND_2), SD1.G3 (GND_3), SD1.P6 (VSS), SD2.6 (VSS), SW1.1, SW1.2, TDA1.4 (AGND), U1.1 (GND), USB1.1 (GND), USB1.12 (GND), USB1.13 (SHIELD), USB2.4 (GND1), USB2.8 (GND2), USB2.9 (Shield), VGA1.0, VGA1.5, VGA1.6, VGA1.7, VGA1.8, VGA1.10
unnamed: C7.1, C8.1, R22.1, R24.1
unnamed: C10.1, C11.1, R25.1, R26.1
unnamed: C13.2, R31.1
unnamed: C16.1, R46.2
unnamed: COM1.1, COM1.4, COM1.6
unnamed: D7.2 (A), Q2.3 (C), R28.2, R30.1
unnamed: D7.1 (K), Q2.1 (B), R31.2
unnamed: GP1.2, R12.2
unnamed: GP2.2, R13.2
unnamed: HDMI1.12 (CLKN), R14.1
unnamed: HDMI1.10 (CLKP), R15.1
unnamed: HDMI1.9 (D0N), R16.1
unnamed: HDMI1.7 (D0P), R17.1
unnamed: HDMI1.6 (D1N), R18.1
unnamed: HDMI1.4 (D1P), R19.1
unnamed: HDMI1.3 (D2N), R20.1
unnamed: HDMI1.1 (D2P), R21.1
unnamed: JP1.1 (A), PSR1.2 (SO/SIO)
unnamed: JP2.1 (A), RP1.36 (3V3)
unnamed: L1.2 (A), R3.1
unnamed: Q1.1 (B), R30.2
unnamed: R37.2, R40.2, VGA1.1
unnamed: R38.2, R41.2, VGA1.2
unnamed: R39.2, R42.2, VGA1.3
unnamed: R43.1, VGA1.13
unnamed: R44.1, VGA1.14
unnamed: R45.2, R46.1, R47.2, R48.2
unnamed: R48.1, R49.2, R50.2
unnamed: R50.1, R51.2, R52.2
unnamed: R52.1, R53.2, R54.2
unnamed: R54.1, R55.2, R56.2
unnamed: R56.1, R57.2, R58.2
unnamed: C9.1, TDA1.7 (FLT)
unnamed: R1.2, USB1.4 (CC1)
unnamed: R2.2, USB1.10 (CC2)
unnamed: R33.2, USB2.3 (D1+)
unnamed: R35.2, USB2.2 (D1-)
unnamed: R34.2, USB2.7 (D2+)
unnamed: R36.2, USB2.6 (D2-)
VBUS: C1.1, C3.1, C5.1, C14.1, C15.1, C17.2, CON2.3, CON3.2, GP1.6, GP2.6, HDMI1.18 (+5V), J1.24, KB1.4, MAX1.16 (VCC), R4.1, R7.1, R8.1, R9.1, RP1.40 (VBUS), TDA1.5 (VA), U1.3 (VI), USB1.2 (VBUS), USB1.11 (VBUS), USB2.1 (VBUS1), USB2.5 (VBUS2)

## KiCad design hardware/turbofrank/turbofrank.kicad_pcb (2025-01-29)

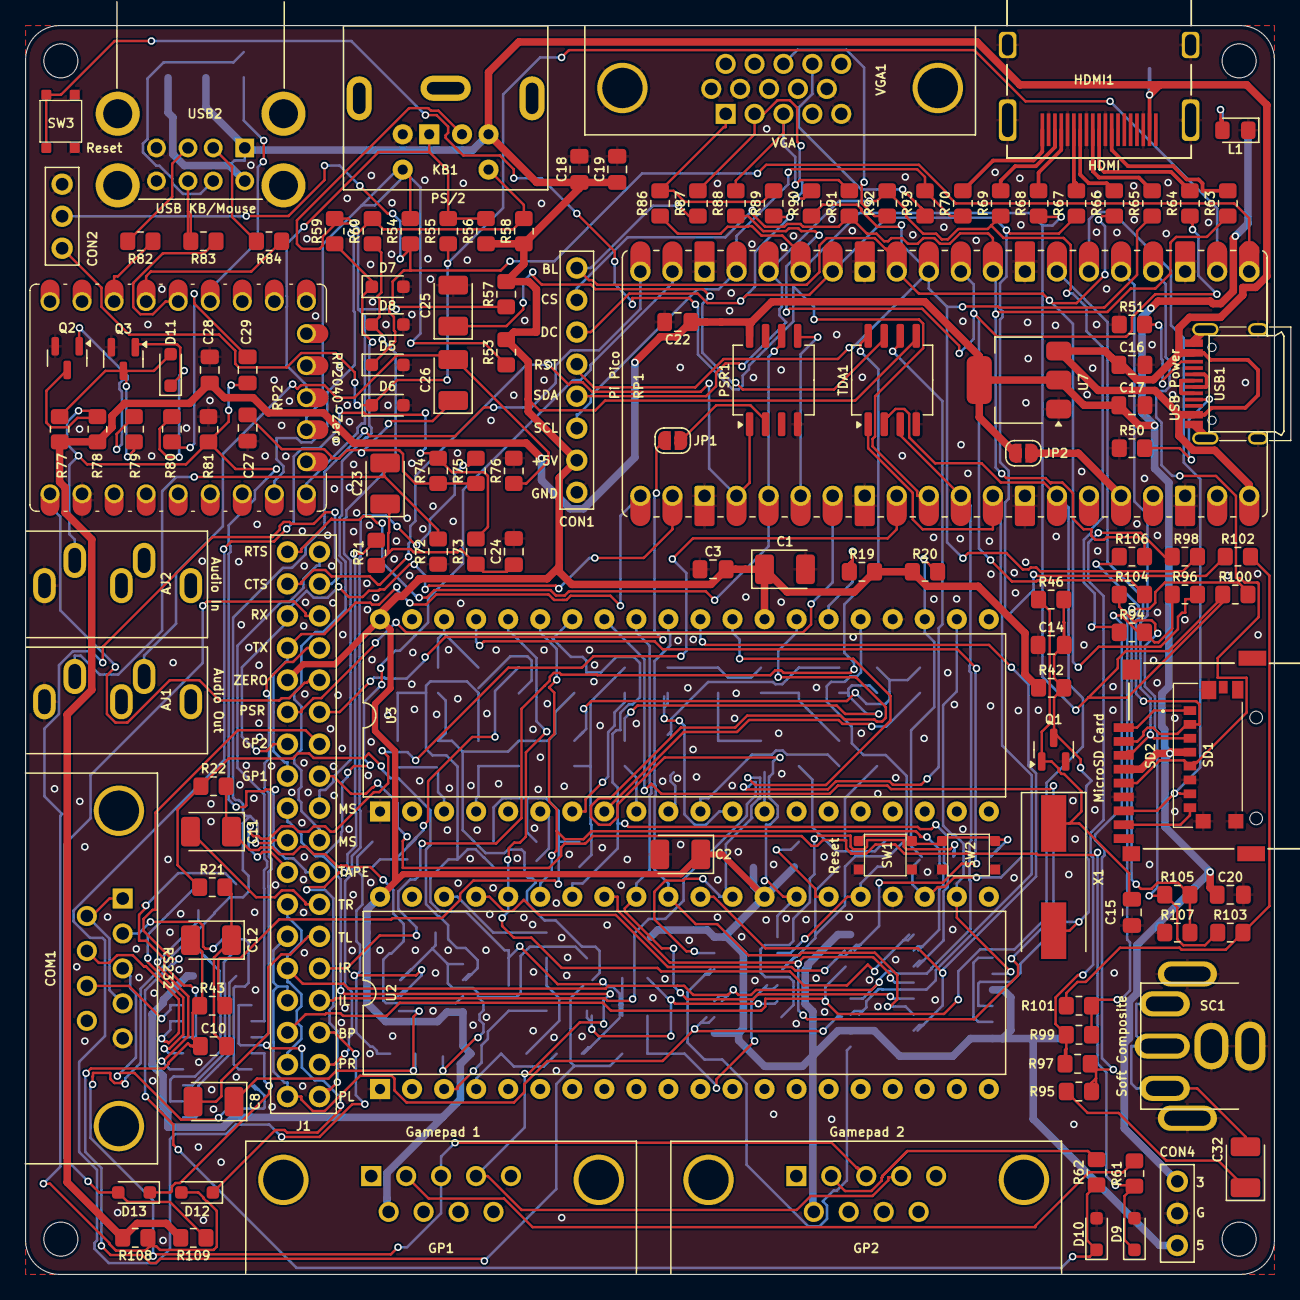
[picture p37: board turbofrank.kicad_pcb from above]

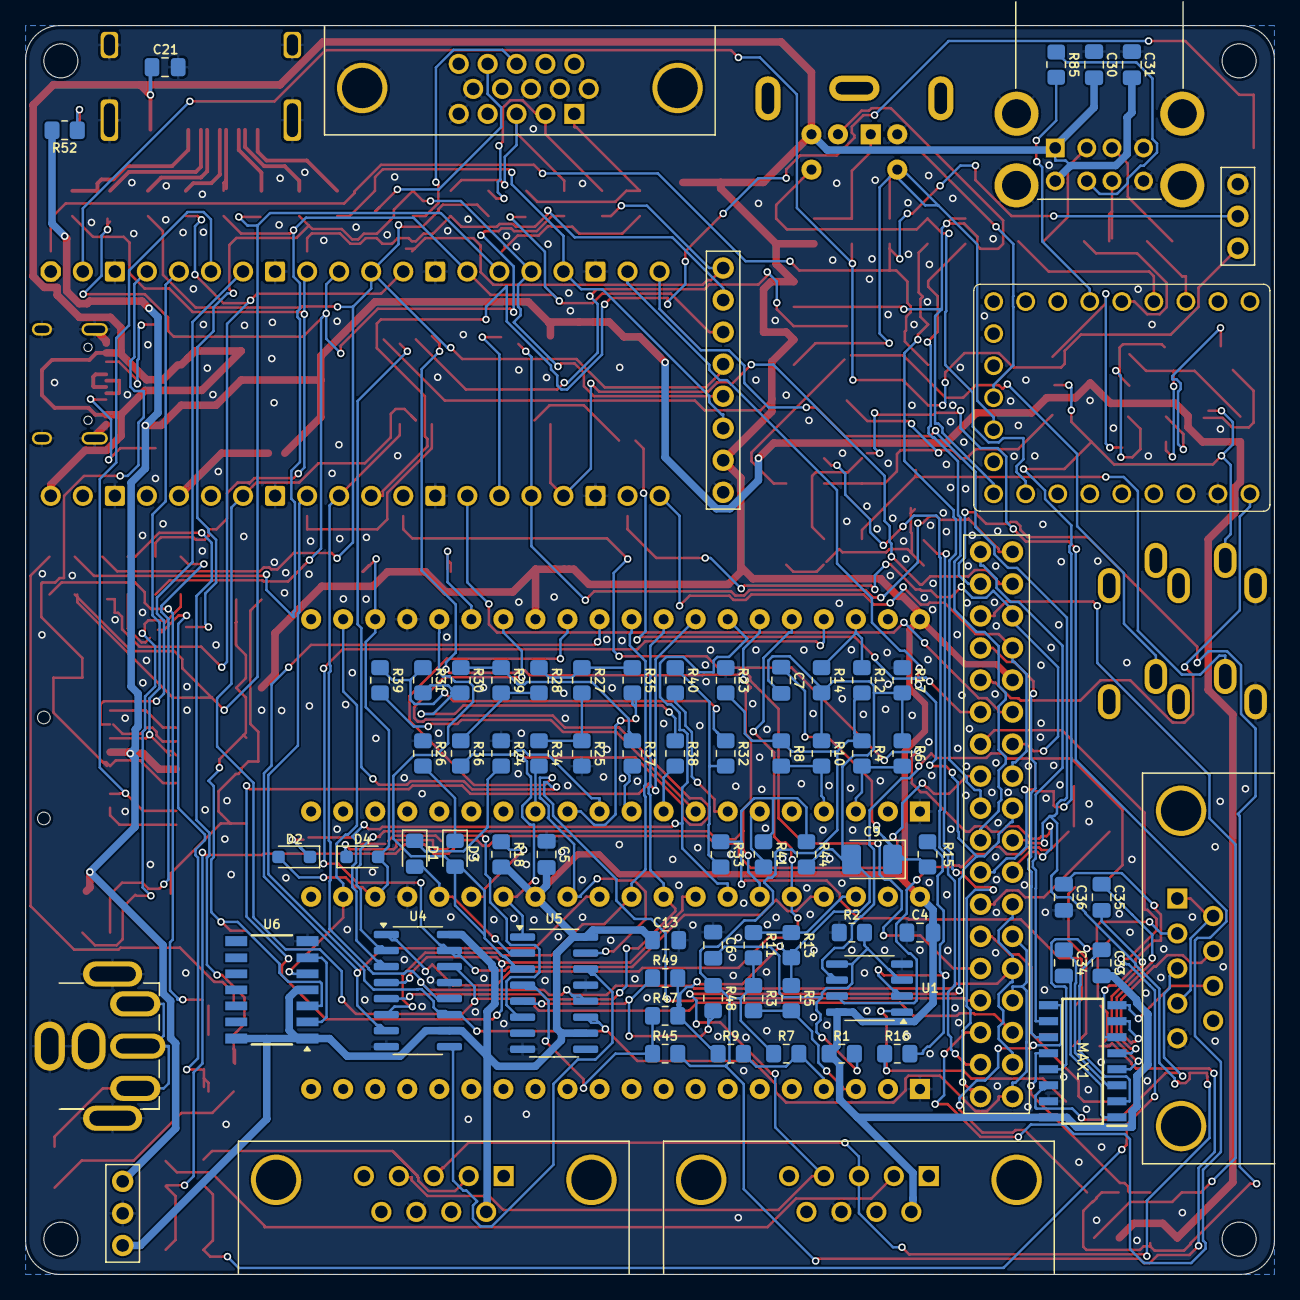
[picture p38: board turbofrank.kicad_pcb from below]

Board: 2 copper layers, 99.0 x 99.0 mm, 201 parts (66 on the bottom side), 171 nets.

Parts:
AJ1: Audio Out; Jack (3.5mm)
AJ2: Audio In; Jack (3.5mm)
C1, C2: 100u; Capacitor (3528, tantalum, polar)
C3, C5, C7, C10, C18, C19, C20, C21, C22, C28, C29: 100n; Capacitor (0805)
C4, C6, C16, C17, C30, C31: 10u; Capacitor (0805)
C8, C9, C11, C12: 10u; Capacitor (3528, tantalum, polar)
C13: 0.1; Capacitor (0805)
C14, C15: 22p; Capacitor (0805)
C23, C25, C26: 10u*; Capacitor (3528, tantalum, polar)
C24, C27: 10n; Capacitor (0805)
C32: 220u; Capacitor (3528, tantalum, polar)
C33, C34, C35, C36: 1u; Capacitor (0805)
COM1: RS232; D-SUB (9 pin, male, top mount)
CON1: Display; Pin Header (1x08)
CON2: UART; Pin Header (1x03)
CON4: Power; Pin Header (1x03)
D1, D3: LED; LED (0805)
D2, D4: 1N4148W; Diode (SOD-323)
D5, D6, D7, D8, D9, D10: 3V3; Diode (SOD-323)
D11, D12, D13: 1N4148; Diode (SOD-323)
GP1, GP2: Gamepad; D-SUB (9 pin, male, top mount)
H1, H2, H3, H4: MountingHole; Mounting Hole (2.7mm)
HDMI1: HDMI Female; HDMI (female)
J1: Main Jumper Set; Pin Header (2x18)
JP1, JP2: Jumper PSRAM (2.54); Jumper (solder)
KB1: PS/2; MiniDIN (6 Pin, female)
L1: GREEN; LED (0805)
MAX1: MAX232CSE+; SOIC127P600X175-16N
PSR1: ESP-PSRAM32; SOIC-8
Q1, Q2, Q3: BC850; SOT-23
R1, R2, R46: 100K; Resistor (0805)
R3, R4, R5, R6, R7, R8, R9, R10, R11, R12, R13, R14, R73, R74: 2K; Resistor (0805)
R15, R20, R21, R43, R44, R45, R47, R48, R49, R77, R79, R80: 10K; Resistor (0805)
R16, R22: 47K; Resistor (0805)
R17, R23: 120R; Resistor (0805)
R18, R19, R24, R26, R42, R52, R53, R57, R58, R61, R62, R71, R75, R78, R108, R109: 1K; Resistor (0805)
R25, R34, R35, R36, R37, R38, R39, R40, R41: 2R; Resistor (0805)
R27, R28, R29, R30, R31, R32, R33: 1R; Resistor (0805)
R50, R51: 5.1K; Resistor (0805)
R54, R55, R59, R60, R81, R92, R93: 100R; Resistor (0805)
R56, R89, R90, R91: 1k; Resistor (0805)
R63, R64, R65, R66, R67, R68, R69, R70, R96, R98, R100, R102, R104, R106: 270R; Resistor (0805)
R72, R76, R86, R87, R88: 330R; Resistor (0805)
R82, R83, R84, R85: 22R; Resistor (0805)
R94: 750R; Resistor (0805)
R95: 51R*; Resistor (0805)
R97, R99, R101, R103, R105: 150R; Resistor (0805)
R107: 300R; Resistor (0805)
RP1: RP Pico; Raspberry Pi Pico
RP2: RP 2040 Zero; Raspberry Pi Zero
SC1: VIDEO (Soft Composite); RCA
SD1: Micro SD (Short); MicroSD (SMD, short)
SD2: Micro SD (Long); MicroSD (SMD, long)
SW1, SW2: SW_Push; Button (SMD, 3x3mm, 1-1)
SW3: Reset Button; Button (SMD, 3x3mm)
TDA1: TDA1387T; SOIC-8
U1: LM358; SO-8
U2, U3: YM2149; DIP-40
U4, U5: 74HC595; SOP-16
U6: 74HC74; 74HCT74D
U7: NCP1117 3.3; SOT-223
USB1: USB Type C
USB2: USB_A_Stacked; USB Type A (stacked)
VGA1: VGA; D-SUB (15 pin, female)
X1: 3.58 MHz; Crystal (HC49-S)

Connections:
+3V3: C17.1, C20.2, C22.1, C28.1, CON4.1, JP2.2 (B), PSR1.8 (VCC), R52.2, R77.1, R78.1, R108.2, R109.2, SD1.P4 (VDD), SD2.4 (VDD), U7.2 (VO)
/A_OUTB: J1.5, R73.2, R74.2
/A_OUTL: J1.1, R71.2
/A_OUTR: J1.3, R75.2
/A_TDAL: J1.7, TDA1.6 (A_LEFT)
/A_TDAR: J1.9, TDA1.8 (A_RIGHT)
/A_TSL: C8.2, J1.11
/A_TSR: C11.2, J1.13
/Audio Out/L: AJ1.T, C23.2, R72.1
/Audio Out/R: AJ1.R, C26.2, R76.1
/Audio Out/TurboSound/A1: R7.2, R9.2, U2.4 (B)
/Audio Out/TurboSound/A2: R8.2, R10.2, U3.4 (B)
/Audio Out/TurboSound/B1: R3.2, R5.2, U2.3 (A)
/Audio Out/TurboSound/B2: R4.2, R6.2, U3.3 (A)
/Audio Out/TurboSound/BEEP: R45.2, R47.2, U5.4 (QE)
/Audio Out/TurboSound/C1: R11.2, R13.2, U2.38 (C)
/Audio Out/TurboSound/C2: R12.2, R14.2, U3.38 (C)
/Audio Out/TurboSound/CLK_1.75M: U2.22 (CLOCK), U3.22 (CLOCK), U6.5 (Q)
/Audio Out/TurboSound/COVOX_OUT: R33.2, R41.1, R43.2, R44.2
/Audio Out/TurboSound/DA0: U2.37 (DA0), U3.37 (DA0), U4.15 (QA)
/Audio Out/TurboSound/DA1: U2.36 (DA1), U3.36 (DA1), U4.1 (QB)
/Audio Out/TurboSound/DA2: U2.35 (DA2), U3.35 (DA2), U4.2 (QC)
/Audio Out/TurboSound/DA3: U2.34 (DA3), U3.34 (DA3), U4.3 (QD)
/Audio Out/TurboSound/DA4: U2.33 (DA4), U3.33 (DA4), U4.4 (QE)
/Audio Out/TurboSound/DA5: U2.32 (DA5), U3.32 (DA5), U4.5 (QF)
/Audio Out/TurboSound/DA6: U2.31 (DA6), U3.31 (DA6), U4.6 (QG)
/Audio Out/TurboSound/DA7: U2.30 (DA7), U3.30 (DA7), U4.7 (QH)
/Audio Out/TurboSound/DAC0: R34.2, U3.13 (IOB0)
/Audio Out/TurboSound/DAC1: R35.2, U3.12 (IOB1)
/Audio Out/TurboSound/DAC2: R36.2, U3.11 (IOB2)
/Audio Out/TurboSound/DAC3: R37.2, U3.10 (IOB3)
/Audio Out/TurboSound/DAC4: R38.2, U3.9 (IOB4)
/Audio Out/TurboSound/DAC5: R39.2, U3.8 (IOB5)
/Audio Out/TurboSound/DAC6: R40.2, U3.7 (IOB6)
/Audio Out/TurboSound/DAC7: R41.2, U3.6 (IOB7)
/Audio Out/TurboSound/L_IN: C7.1, C9.2, R5.1, R6.1, R9.1, R10.1, R13.1, R14.1, R17.1, R44.1, R47.1, R49.1
/Audio Out/TurboSound/R_IN: C10.1, C12.2, R3.1, R4.1, R7.1, R8.1, R11.1, R12.1, R23.1, R43.1, R45.1, R48.1
/Audio Out/TurboSound/SAVE: R48.2, R49.2, U5.5 (QF)
/Audio Out/TurboSound/YM_BC1: U2.29 (BC1), U3.29 (BC1), U5.15 (QA)
/Audio Out/TurboSound/YM_BDIR: U2.27 (BDIR), U3.27 (BDIR), U5.1 (QB)
/Audio Out/TurboSound/YM_CS1: D1.2 (A), U2.25 (A8), U5.2 (QC)
/Audio Out/TurboSound/YM_CS2: D3.2 (A), U3.25 (A8), U5.3 (QD)
/Audio Out/TurboSound/YM_RST: D2.2 (A), D4.2 (A), R20.1, U2.23 (~RESET), U3.23 (~RESET)
/Audio Out/TurboSound/YM_SEL1: R18.2, U2.26 (~SEL)
/Audio Out/TurboSound/YM_SEL2: R19.2, U3.26 (~SEL)
/Composite/CVBS: C32.2, SC1.1
/GP1_DATA: D9.1 (K), J1.21, R61.1
/GP2_DATA: D10.1 (K), J1.23, R62.1
/GPIO0: CON2.2, D5.1 (K), R54.2, RP1.1 (GPIO0)
/GPIO1: CON2.3, D6.1 (K), R55.2, RP1.2 (GPIO1)
/GPIO2: RP1.4 (GPIO2), SD1.P5 (CLK), SD2.5 (CLK)
/GPIO3: RP1.5 (GPIO3), SD1.P3 (CMD), SD2.3 (CMD)
/GPIO4: RP1.6 (GPIO4), SD1.P7 (DAT0), SD2.7 (DAT0)
/GPIO5: RP1.7 (GPIO5), SD1.P2 (CD/DAT3), SD2.2 (DAT3/CD)
/GPIO6: CON1.7, R63.2, R91.1, R106.1, RP1.9 (GPIO6)
/GPIO7: R64.2, R88.1, R104.1, RP1.10 (GPIO7)
/GPIO8: CON1.5, R65.2, R90.1, R98.1, RP1.11 (GPIO8)
/GPIO9: CON1.8, R66.2, R87.1, R96.1, RP1.12 (GPIO9)
/GPIO10: CON1.6, R67.2, R89.1, R102.1, RP1.14 (GPIO10)
/GPIO11: R68.2, R86.1, R100.1, RP1.15 (GPIO11)
/GPIO12: CON1.4, R69.2, R92.2, R94.1, RP1.16 (GPIO12)
/GPIO13: CON1.3, R70.2, R93.2, RP1.17 (GPIO13)
/GPIO14: GP1.4, GP2.4, J1.20, RP1.19 (GPIO14)
/GPIO15: GP1.3, GP2.3, J1.18, RP1.20 (GPIO15)
/GPIO16: J1.22, J1.30, RP1.21 (GPIO16)
/GPIO17: J1.24, J1.32, RP1.22 (GPIO17)
/GPIO18: J1.34, PSR1.1 (~CE), RP1.24 (GPIO18)
/GPIO19: J1.36, PSR1.6 (SCLK), RP1.25 (GPIO19)
/GPIO20: PSR1.5 (SI/SIO), RP1.26 (GPIO20)
/GPIO21: J1.26, RP1.27 (GPIO21)
/GPIO22: J1.16, RP1.29 (GPIO22)
/GPIO26: J1.4, J1.10, J1.14, RP1.31 (GPIO26_ADC0), TDA1.3 (DATA), U4.12 (RCLK), U5.12 (RCLK)
/GPIO27: J1.2, J1.8, J1.12, RP1.32 (GPIO27_ADC1), TDA1.1 (SCLK), U4.11 (SRCLK), U5.11 (SRCLK)
/GPIO28: J1.6, RP1.34 (GPIO28_ADC2), TDA1.2 (LRCK), U4.14 (SER)
/KB_CLK: KB1.5, R53.2, R54.1, RP2.13 (12)
/KB_DATA: KB1.1, R55.1, R56.2, RP2.12 (11)
/LOAD_IN_D: AJ2.T, C29.1, J1.15, Q2.3 (C), R78.2, R81.1
/MS_CLK: KB1.6, R58.2, R60.1, RP2.16 (15)
/MS_CLK_3V: D8.1 (K), J1.19, R60.2
/MS_DATA: KB1.2, R57.2, R59.1, RP2.15 (14)
/MS_DATA_3V: D7.1 (K), J1.17, R59.2
/Micro SD/DAT1: SD1.P8 (DAT1), SD2.8 (DAT1)
/Micro SD/DAT2: SD1.P1 (DAT2), SD2.1 (DAT2)
/PSR_SOSIO: J1.25, JP1.2 (B)
/Power/D+: USB1.6 (DP1), USB1.8 (DP2)
/Power/D-: USB1.5 (DN2), USB1.7 (DN1)
/RS232/C1+: C34.2, MAX1.1 (C1+)
/RS232/C1-: C34.1, MAX1.3 (C1-)
/RS232/C2+: C35.2, MAX1.4 (C2+)
/RS232/C2-: C35.1, MAX1.5 (C2-)
/RS232/CTS_IN: COM1.7, MAX1.7 (T2OUT)
/RS232/CTS_MAX: D12.1 (K), MAX1.9 (R2OUT)
/RS232/RTS_IN: COM1.8, MAX1.8 (R2IN)
/RS232/RX_IN: COM1.3, MAX1.14 (T1OUT)
/RS232/RX_MAX: D13.1 (K), MAX1.12 (R1OUT)
/RS232/TX_IN: COM1.2, MAX1.13 (R1IN)
/RS232/V+: C33.1, MAX1.2 (V+)
/RS232/V-: C36.1, MAX1.6 (V-)
/RS232_CTS: D12.2 (A), J1.33, R108.1
/RS232_RTS: J1.35, MAX1.10 (T2IN)
/RS232_RX: D13.2 (A), J1.31, R109.1
/RS232_TX: J1.29, MAX1.11 (T1IN)
/RUN: RP1.30 (RUN), SW3.3, SW3.4
/USB_D1M: R84.1, RP2.4 (3)
/USB_D1P: R82.1, RP2.3 (2)
/USB_D2M: R85.1, RP2.6 (5)
/USB_D2P: R83.1, RP2.5 (4)
/ZERO_VBUS: J1.27, RP2.23 (5V)
GND: AJ1.S, AJ2.S, C1.2, C2.2, C3.2, C4.2, C5.2, C6.2, C13.2, C14.1, C15.1, C16.2, C17.2, C18.2, C19.2, C20.1, C21.2, C22.2, C24.2, C25.2, C27.2, C28.2, C30.2, C31.2, C36.2, COM1.5, CON1.1, CON2.1, CON4.2, D5.2 (A), D6.2 (A), D7.2 (A), D8.2 (A), D9.2 (A), D10.2 (A), GP1.8, GP2.8, HDMI1.2 (G_D2), HDMI1.5 (G_D1), HDMI1.8 (G_D0), HDMI1.11 (G_CLK), HDMI1.17 (G_DDC/CEC), HDMI1.20 (SHIELD1), HDMI1.21 (SHIELD2), HDMI1.22 (SHIELD3), HDMI1.23 (SHIELD4), KB1.3, L1.1 (K), MAX1.15 (GND), PSR1.4 (VSS), Q1.2 (E), Q2.2 (E), Q3.2 (E), R2.2, R17.2, R23.2, R24.1, R25.1, R26.1, R50.1, R51.1, R72.2, R76.2, R81.2, R107.1, RP1.3 (GND), RP1.8 (GND), RP1.13 (GND), RP1.18 (GND), RP1.23 (GND), RP1.28 (GND), RP1.33 (AGND), RP1.38 (GND), RP2.22 (GND), SC1.2, SD1.G1 (GND_1), SD1.G2 (GND_2), SD1.G3 (GND_3), SD1.P6 (VSS), SD2.6 (VSS), SW1.2, SW2.2, SW3.1, SW3.2, TDA1.4 (AGND), U1.4 (V-), U2.1 (VSS), U2.24 (~A9), U3.1 (VSS), U3.24 (~A9), U4.8 (GND), U4.13 (~OE), U5.8 (GND), U5.13 (~OE), U6.7 (GND), U7.1 (GND), USB1.1 (GND), USB1.12 (GND), USB1.13 (SHIELD), USB2.4 (GND1), USB2.8 (GND2), USB2.9 (Shield), VGA1.0, VGA1.5, VGA1.6, VGA1.7, VGA1.8, VGA1.10
unnamed: C7.2, C9.1, R15.2
unnamed: C8.1, R16.1, U1.1
unnamed: C10.2, C12.1, R21.2
unnamed: C11.1, R22.1, U1.7
unnamed: C23.1, C24.1, R71.1, R73.1
unnamed: C26.1, C27.1, R74.1, R75.1
unnamed: C29.2, R80.1
unnamed: C32.1, R95.2
unnamed: COM1.1, COM1.4, COM1.6
unnamed: D1.1 (K), R24.2
unnamed: D2.1 (K), SW1.1, SW2.1
unnamed: D3.1 (K), R26.2
unnamed: D4.1 (K), U5.6 (QG)
unnamed: D11.2 (A), Q3.3 (C), R77.2, R79.1
unnamed: D11.1 (K), Q3.1 (B), R80.2
unnamed: GP1.2, R61.2
unnamed: GP2.2, R62.2
unnamed: HDMI1.12 (CLKN), R63.1
unnamed: HDMI1.10 (CLKP), R64.1
unnamed: HDMI1.9 (D0N), R65.1
unnamed: HDMI1.7 (D0P), R66.1
unnamed: HDMI1.6 (D1N), R67.1
unnamed: HDMI1.4 (D1P), R68.1
unnamed: HDMI1.3 (D2N), R69.1
unnamed: HDMI1.1 (D2P), R70.1
unnamed: JP1.1 (A), PSR1.2 (SO/SIO)
unnamed: JP2.1 (A), RP1.36 (3V3)
unnamed: L1.2 (A), R52.1
unnamed: C15.2, Q1.1 (B), R46.1, X1.1
unnamed: C14.2, Q1.3 (C), R42.1, R46.2, U6.3 (C), X1.2
unnamed: Q2.1 (B), R79.2
unnamed: R25.2, R27.1, R34.1
unnamed: R27.2, R28.1, R35.1
unnamed: R28.2, R29.1, R36.1
unnamed: R29.2, R30.1, R37.1
unnamed: R30.2, R31.1, R38.1
unnamed: R31.2, R32.1, R39.1
unnamed: R32.2, R33.1, R40.1
unnamed: R86.2, R89.2, VGA1.1
unnamed: R87.2, R90.2, VGA1.2
unnamed: R88.2, R91.2, VGA1.3
unnamed: R92.1, VGA1.13
unnamed: R93.1, VGA1.14
unnamed: R94.2, R95.1, R96.2, R97.2
unnamed: R97.1, R98.2, R99.2
unnamed: R99.1, R100.2, R101.2
unnamed: R101.1, R102.2, R103.2
unnamed: R103.1, R104.2, R105.2
unnamed: R105.1, R106.2, R107.2
unnamed: C25.1, TDA1.7 (FLT)
unnamed: C6.1, R1.2, R2.1, U1.3 (+), U1.5 (+)
unnamed: R15.1, R16.2, U1.2 (-)
unnamed: R21.1, R22.2, U1.6 (-)
unnamed: U4.9 (QH'), U5.14 (SER)
unnamed: U6.2 (D), U6.6 (~Q)
unnamed: R50.2, USB1.4 (CC1)
unnamed: R51.2, USB1.10 (CC2)
unnamed: R82.2, USB2.3 (D1+)
unnamed: R84.2, USB2.2 (D1-)
unnamed: R83.2, USB2.7 (D2+)
unnamed: R85.2, USB2.6 (D2-)
VBUS: C1.1, C2.1, C3.1, C4.1, C5.1, C13.1, C16.1, C18.1, C19.1, C21.1, C30.1, C31.1, C33.2, CON1.2, CON4.3, GP1.6, GP2.6, HDMI1.18 (+5V), J1.28, KB1.4, MAX1.16 (VCC), R1.1, R18.1, R19.1, R20.2, R42.2, R53.1, R56.1, R57.1, R58.1, RP1.40 (VBUS), TDA1.5 (VA), U1.8 (V+), U2.28 (BC2), U2.40 (VCC), U3.28 (BC2), U3.40 (VCC), U4.10 (~SRCLR), U4.16 (VCC), U5.10 (~SRCLR), U5.16 (VCC), U6.1 (~R), U6.4 (~S), U6.14 (VCC), U7.3 (VI), USB1.2 (VBUS), USB1.11 (VBUS), USB2.1 (VBUS1), USB2.5 (VBUS2)

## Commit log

2024-08-21 3D Models added
    [Micro_SD_Card_and_Holder.stp, Mini-DIN-6P.step, PICO_PinsDown.STEP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]
2024-08-21 Scheme & PCB updates
    [CMZJ2.kicad_pcb, CMZJ2.kicad_sch]
2024-08-21 AV Video output added
    [CMZJ2.kicad_pcb, CMZJ2.kicad_sch, CUI_DEVICES_RCJ-013.step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]
2024-08-22 Added HDMI port
    [CMZJ2.kicad_pcb, CMZJ2.kicad_sch]
2024-08-23 New HW revision
    [CMZJ2.kicad_pcb, CMZJ2.kicad_sch]
2024-08-24 Work in progress
    [CMZJ2.kicad_pcb, CMZJ2.kicad_sch]
2024-08-26 Revision updates
    [CMZJ2.kicad_pcb, CMZJ2.kicad_sch, MAX232CSE+.stp]
2024-08-26 HW Rev 1.0 Preview
    [CMZJ2.kicad_sch]
2024-08-27 HW REV 1.0
    [CMZJ2.kicad_pcb, CMZJ2.kicad_sch, HRO_TYPE-C-31-M-12.step]
2024-08-27 HW 1.01
    [CMZJ2.kicad_pcb]
2024-08-27 HW Rev 1.02
    [CMZJ2.kicad_pcb]
2024-08-27 HW Rev. 1.04
    [CMZJ2.kicad_pcb]
2024-09-04 Minor updates
    [CMZJ2.kicad_pcb]
2024-09-04 HW Version 1.5
    [CMZJ2.kicad_pcb, CMZJ2.kicad_sch]
2024-09-04 HW 1.6 WIP
    [CMZJ2.kicad_pcb, CMZJ2.kicad_sch]
2024-09-05 HW Rev. 1.6 WIP
    [CMZJ2.kicad_pcb]
2024-09-08 Changed MAX232 to level shifter
    [CMZJ2.kicad_pcb, CMZJ2.kicad_sch, level_shifter.kicad_sch]
2024-09-08 HW Version 1.8
    [CMZJ2.kicad_pcb, old.kicad_sch]
2024-09-09 HW Revision 1.8
    [CMZJ2.kicad_pcb]
2024-09-09 Removed/archived unused files
    [level_shifter.kicad_sch, old.kicad_sch]
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2024-09-10 HW Rev 1.08
    [CMZJ2.kicad_pcb, CMZJ2.kicad_sch]
2024-10-02 HW Rev 1.09
    [CMZJ2.kicad_pcb, CMZJ2.kicad_sch, level_shifter.kicad_sch]
2024-10-04 MAX232-related changes
    [CMZJ2.kicad_pcb, CMZJ2.kicad_sch]
2024-10-04 HW Rev 1.10
    [CMZJ2.kicad_pcb, CMZJ2.kicad_sch]
2024-10-23 HW Rev 1.12
    [CMZJ2.kicad_pcb, CMZJ2.kicad_sch]
2024-11-22 Minor fixes
    [CMZJ2.kicad_pcb, Header_Female_single_15.STEP, PICO Clone-Black .step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]
2025-01-12 Master branch cleanup
    [CMZJ2.csv, CMZJ2.kicad_pcb, CMZJ2.kicad_sch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]
2025-01-31 HW Rev 1.0 work-in-progress
    [3v.kicad_sch, RP2350_60QFN_minimal.kicad_sch, audio.kicad_sch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]
2025-01-31 Frank M2 HW Rev 1.0
    [3v.kicad_sch, 47571-0001.stp, DSUB-9_Female_Horizontal_P2.77x2.84mm_EdgePinOffset9.90mm_Housed_MountingHolesOffset11.32mm.step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]
2025-02-02 Fixed audio pins
    [audio.kicad_sch, composite.kicad_sch, display.kicad_sch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]
2025-02-02 HW Rev 1.01
    [audio.kicad_sch, audio_out_m1.kicad_sch, composite.kicad_sch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]
2025-02-02 HW Rev 1.2
    [frank-m2-2350A.kicad_pcb, rp2350a.kicad_sch]
2025-02-02 HW Rev 2.01
    [button.kicad_sch, hdmi.kicad_sch, power.kicad_sch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]
2025-02-03 FRANK M1 work-in-progress
    [DSUB-9_Female_Horizontal_P2.77x2.84mm_EdgePinOffset9.90mm_Housed_MountingHolesOffset11.32mm.step, HRO_TYPE-C-31-M-12.step, Mini-DIN-6P.step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]
2025-02-04 FRANK M1 HW Rev 1.00
    [47571-0001.stp, Micro_SD_Card_and_Holder.stp, audio_out_m1.kicad_sch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]
2025-02-05 FRANK M2U WIP
    [3v.kicad_sch, 47571-0001.stp, DSUB-9_Female_Horizontal_P2.77x2.84mm_EdgePinOffset9.90mm_Housed_MountingHolesOffset11.32mm.step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]
2025-02-06 FRANK M2U HW Rev 1.00
    [audio_out_m1.kicad_sch, crystal_12mhz.kicad_sch, frank-m2u-2350A.kicad_pcb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]
2025-02-18 FRANK WIP
    [47571-0001.stp, CMZJ2.csv, CMZJ2.kicad_pcb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]
2025-02-18 Names changed
    [3v.kicad_sch, 47571-0001.stp, CMZJ2.kicad_pcb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]
2025-02-19 Added archive directory
    [CMZJ2.kicad_pcb, CMZJ2.kicad_sch, CMZJ2.xlsx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]
2025-02-19 FRANK M1 & M2 HW Revisions
    [CMZJ2.kicad_pcb, CMZJ2.kicad_sch, HR3FQ.kicad_pcb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]
2025-02-19 USB2PS2 Zero HW REV 1.1
    [bottom.stl, ps2d.kicad_sch, top.stl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]
2025-02-21 Moved RM2(x) versions to archive
    [3v.kicad_sch, 47571-0001.stp, DSUB-9_Female_Horizontal_P2.77x2.84mm_EdgePinOffset9.90mm_Housed_MountingHolesOffset11.32mm.step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]
2025-02-22 FRANK RM2 WIP
    [3v.kicad_sch, RP2350_60QFN_minimal.kicad_sch, audio.kicad_sch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]
2025-02-23 MiniFRANK RM2 HW 1.03
    [47571-0001.stp, DSUB-9_Female_Horizontal_P2.77x2.84mm_EdgePinOffset9.90mm_Housed_MountingHolesOffset11.32mm.step, HRO_TYPE-C-31-M-12.step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]
2025-02-24 Case for 1.01 added
    [bottom.stl, top.stl]
2025-03-03 Versa renamed to Protea
    [DSUB-9_Female_Horizontal_P2.77x2.84mm_EdgePinOffset9.90mm_Housed_MountingHolesOffset11.32mm.step, HRO_TYPE-C-31-M-12.step, MAX232CSE+.stp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]
2025-03-03 Protea HW Rev 2.02
    [protea.kicad_pcb]
2025-03-03 HW Rev 1.14
    [CMZJ2.kicad_pcb, CMZJ2.kicad_sch, audio.kicad_sch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]
2025-03-03 HW Rev 1.02 (M2)
    [HR3FQ.kicad_pcb, HR3FQ.kicad_sch, audio.kicad_sch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]
2025-03-03 Protea case added
    [bottom.stl, top.stl]
2025-03-03 HDMI2VGA HW 2.01
    [418117270906.stp, 47571-0001.stp, DS1037-9F.STEP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]
2025-03-04 Structural updates
    [3v.kicad_sch, 47571-0001.stp, CMZJ2.kicad_pcb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]
2025-03-04 RM1 HW 2.01
    [audio.kicad_sch, gamepad.kicad_sch, hdmi.kicad_sch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]
2025-03-04 Moving archives to ZIP files
    [3v.kicad_sch, 47571-0001.stp, CMZJ2.kicad_pcb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]
2025-03-04 MiniFRANK updates
    [audio_out_m1.kicad_sch, crystal_12mhz.kicad_sch, frank_m1.kicad_pcb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]
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2025-03-05 FRANK RM1Z HW 1.00
    [47571-0001.stp, CUI_DEVICES_RCJ-013.step, DSUB-15-HD_Male_Horizontal_P2.29x1.98mm_EdgePinOffset3.03mm_Housed_MountingHolesOffset4.94mm.step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]
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2025-03-14 RM24 minor fixes
    [audio_out_m1.kicad_sch, frank_rm24.kicad_pcb, frank_rm24.kicad_sch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]

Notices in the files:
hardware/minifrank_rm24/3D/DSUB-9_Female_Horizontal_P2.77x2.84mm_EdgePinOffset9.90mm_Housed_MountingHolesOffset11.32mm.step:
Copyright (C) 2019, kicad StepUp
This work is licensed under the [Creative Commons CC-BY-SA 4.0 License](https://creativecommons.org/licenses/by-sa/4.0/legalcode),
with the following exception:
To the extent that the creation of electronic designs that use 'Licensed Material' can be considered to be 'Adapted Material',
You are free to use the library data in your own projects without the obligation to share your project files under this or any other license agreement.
